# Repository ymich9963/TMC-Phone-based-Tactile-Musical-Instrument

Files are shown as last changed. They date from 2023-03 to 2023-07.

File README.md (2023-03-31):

# TMC: Phone-based Tactile Musical Instrument
A Theremin MIDI Controller made with an HC-SR04 and SingleTact pressure sensors connected to an Arduino Micro. A USB cable is required in order for the hardware and phone to work together.

Created and materialised during the 4th year of my Electronic & Electrical Engineering degree at the University of Strathclyde.

## 3D Prints
Contains the final 3D prints of the project. The bottom part of casing, the top lid as well as the sliding sensor cover.

## Application
Contains the TMC application source files to rebuild and .apk file to directly install on the Android device.

Source code can be edited by donwloading Android Studio and going to File --> Open and selecting the project folder.

APK file can be installed by enabling installation from unknown sources on the device.

## Documentation
Report that details the creation of the project.

## Microcontroller Code
Made in Arduino IDE and can be edited or re-flashed by copying the folders into the default "C:\Users\<USER>\Documents\Arduino\" directory.

Library required is USB-MIDI.

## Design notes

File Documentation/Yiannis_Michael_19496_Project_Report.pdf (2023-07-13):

## Phone Based Tactile Musical Instrument: Theremin MIDI Controller

## Yiannis Michael

### Supervisor: Dr Gordon Dobie Second Assessor: Dr Rory Hampson

### 31st March 2023

“I hereby declare that this work has not been submitted for any other degree/course at this University or any other institution and that, except where reference is made to the work of other authors, the material presented is original and entirely the result of my own work at the University of Strathclyde under the supervision of Dr. Gordon Dobie.”

## Executive Summary

The project encompassed the creation of a phone-based tactile musical instrument.

Following a detailed market analysis and the initial research stage, a proposal was formed

and the project objectives were defined. A Theremin Musical Instrument Digital Interface

(MIDI) Controller was described as the project solution, which would have a theremin

hardware interface and be able to send MIDI commands to ensure cross-compatibility with

other MIDI software. A companion application would also be created to provide interaction

with the hardware as well as using two of a total of three SingleTact sensors for effects on

the sound output. The final product should be able to play a simple melody like “Amazing

Grace”.

The ultrasonic sensor chosen was the HC-SR04 transmitter and receiver, and along with the

three provided SingleTacts, they were the four sensors used in the project. The sensors sent

readings to the microcontroller of choice, which was the Arduino Micro and was coded in the

Arduino IDE. It was chosen due to its capabilities of Universal Serial Bus (USB)

communication, Analogue to Digital Conversion (ADC) and Inter-Integrated Circuit (I2C)

communication. ADC was used for the HC-SR04, and I2C was used for the SingleTact sensors.

All of the components fit inside the custom-designed 3D casing which had four iterations.

The USB protocol was used for the hardware to communicate with the companion phone

application.

The mobile app was made for the Android ecosystem and was therefore designed using

Android Studio and the Java coding language. Examples provided by the Android developers

were modified to fit project needs, and a custom GUI was also designed for user interaction

with the app. MIDI compatibility was accomplished by using and modifying these examples.

In the case of the microcontroller code, the USB-MIDI Arduino library was used to send MIDI

messages to the application. The application gives four effects which can be set to the two

SingleTact sensors, with the third one being mapped for the volume of the note outputs. The

ultrasonic sensor provides note pitch data which is used to send the corresponding MIDI

command for the app to output the specific note. By using the software and hardware

together, as well as all four sensors, it is possible to play music.

The project was a success with all outlined objectives being fulfilled, as well as the completion

of additional objectives which increase the applications of the final product in the real-world

market of phone-based musical instruments.

## Table of Contents

4.3 Results | 62
5.0 Chapter V – Evaluation | 64
5.1 Discussion | 64
5.2 Conclusion | 67
5.3 Further Work | 68
References | 69
Appendix A – Statement Of Intent | 74
Appendix B – Code | 82
B1: Microcontroller Code | 82
B1.1: TMC_2.ino: | 82
B2: Android Application Code | 90
B2.1 SelectionConfig.java | 90
B2.2 MainActivity.java | 92
B2.3 EnevelopeASDR.java | 100
B2.4: SineVoice.java | 103
B2.5: SineOscillator.java | 105
B2.6: SawVoice.java | 107
B2.7: SawOscillator.java | 109
B2.8: SynthEngine.java | 111
B2.9: AndroidManifest.xml | 120
Appendix C – User Guide | 121

## Table of Tables

## Table of Figures

## 1.0 Chapter I – Research

### 1.1 Introduction

In this report it is explained how a phone-based tactile musical instrument was created, with

detailed analysis of each step in its production. In Chapter I, the initial research stage is

expanded upon. This stage gave some ideas as to which paths this project could have taken

and therefore heavily informed the future decisions after this point. Chapter II documents

the hardware chosen and how they are setup for the final product, as well as how they

interact. Chapter III focuses on the project’s software design with both application code and

microcontroller code. The fourth chapter details how testing was made at each stage and

how solutions were created to either completely remove some problems or to minimise their

effect. Final results in this chapter are also described. Chapter V deals with discussion,

conclusion, and further work.

### 1.2 Background

In order to fully understand and appreciate the goals of this product some general

background information about musical instruments, terminology, and history of music must

be explained. A term used in abundance in this report is the Musical Instrument Digital

Interface (MIDI) communications protocol. The creation of MIDI allowed for a standard

instrument language to be used during development. It was developed in the 1980s and

initially proposed by the Roland founder - Ikutaro Kakehashi - to other digital musical

instrument manufacturers who soon got on board and further developed the standard.

Finally, it was released in 1982 and changed the way electronic instruments were developed

for the next decades to come [1].

In modern music a Digital Audio Workstation (DAW), is a must have tool which greatly

enhances the music creation experience. DAWs are music production software that enable

users to record, edit and manipulate audio files in innumerable ways. They also have the

capabilities of manipulating incoming MIDI data, as well as providing some facilities to test

MIDI like virtual musical instruments or custom routing of incoming MIDI commands [2].

However, MIDI and DAWs are only but recent developments in the musical sphere. The main

instrument types that have existed long before them are string, wind, percussion, brass, and

electronic instruments. Examples of these types of musical instruments could be guitar, flute,

piano, trumpet, and synthesisers. In the case of electronic instruments, their manufacturing

process differs from a traditional musical instrument. Instead of considering acoustic

properties, electrical components are used to either program or create a sound output,

either through the instrument itself or through another machine running a software package.

The way the player interacts with electronic musical instruments is usually very similar to

that of a traditional instrument, a good example of this is an electric piano or an electric

guitar [3].

An electronic musical instrument very relevant to this project is the Theremin. This musical

instrument was invented in the Soviet Union by Leon Theremin in 1920. In the analogue

version of the Theremin, the pitch and volume are controlled by the vertical and horizontal

antennae respectfully. The user can move their hands towards or away from these antennae,

each of which have an electromagnetic field surrounding them, and create interference

which in turn affects the outputted sound [4]. Multiple modernised iterations of the analogue

theremin exist today, but other engineers have created much simpler and cheaper versions

using either the same concepts or with other kinds of sensor equipment [5].

Recent developments have allowed the electronic instrument to only use MIDI and MIDI-

compatible software to generate music. This eliminates the use of large and complex

synthesiser circuits and allows for smaller, lighter but still musical instruments called MIDI

Controllers which as the name suggests, are simply pieces of hardware that send or receive

MIDI data to the corresponding MIDI-compatible destination. A MIDI Controller can be a

device of any size and shape and wireless or wired. The only requirement is the ability to

send MIDI data through whatever communications medium it is designed for [6].

Figure 1 Example of MIDI Controller and DAW usage [1]

Some other general musical terminology used throughout this report are “arpeggio” which

is defined as “the notes of the chords are to be played quickly one after another instead of

simultaneously” and “octave” which is used to describe the “interval between one musical

pitch and another with half or double its frequency” [7]. Some other more musical production

terms used are MPC pads which stands for the Music Production Centre pads, used in a

variety of modern electronic musical instruments [8].

### 1.3 Market Analysis

Market analysis was conducted by looking at all major music instrument retailers worldwide,

and seeing what kind of products are being sold that are similar to the project description.

The seven retailers used were Thomann which is based in Germany, Sweetwater and Guitar

Centre which are based in the USA, Swee Lee which have a variety of locations in Asian

countries, Andertons and Guitarguitar which are based in the UK, and finally Ishibashi Music

which is based in Japan. Search terms such as "for iPhone", "for phone", "mobile", "portable"

etc. were used to specifically showcase the products that are phone-based, or can operate

with the phone as well as have other features. The target audience for this market analysis

were musicians of every level whether they would be beginner, intermediate, advanced or

hobbyists, as well as music producers that may not perform with these instruments but use

them in the music making process.

1.3.1 Instruments

There were numerous phone compatible musical instruments that were noteworthy as

shown in Table 1 . The first one was the IK Multimedia iRig Keys 2 (and size variants) [9].

Using a provided software called SampleTank SE 4, the MIDI messages sent from this MIDI

controller can be outputted as sounds depending on the instrument selected, as well as other

functionality customisations. Another MIDI keyboard that was examined, was the IK

Multimedia iRig Keys I/O (and size variants) [10] which also used the "made for iPhone/iPad"

tagline to signify that it was made with those users and that ecosystem in mind . A similar

keyboard found on the market was the CME Xkey Air (and size variants) [11]. One thing that

differentiated this from other keyboards during the market is the “Polyphonic Aftertouch”

capabilities, which means that the note changes timbre while being played.

A more unique take on the MIDI controller is the LinnStrument MIDI Performance Controller

[12] which is an expressive MIDI controller for musical performance. Finally, two very similar

keyboards that were examined were the Akai Professional MPK Mini MK III [13] and the

Novation Launchkey Mini MK3 [14]. These keyboards encompass the idea of a typical

keyboard MIDI controller that is able to be used with a phone, whilst also being portable and

practical. They have the common features all of the previous MIDI controllers had and if

hundreds of generic MIDI controllers were examined, they would be extremely similar to

these two keyboards.

Table 1 Instruments found relating to the market analysis. Features highlight some unique aspects of each instrument.

Product Name | Features | Price | Short Description
IK Multimedia iRig Keys 2 (and size variants) [9] | • Note sustain button • Assignable knobs • Pitch bend wheel • Modulation wheel • Octave up/down buttons • MIDI IN/OUT • SampleTank SE 4 | £113/£130/£149 | Compatible with Android and iOS devices. Used as a MIDI keyboard to control other sounds and plugins.
IK Multimedia iRig Keys I/O (and size variants) [10] | • "Made for iPhone/iPad" • Same features as IK Multimedia iRig Keys 2 • Built in audio interface | £201/£289 | Used as a MIDI keyboard but a built-in audio interface allows another instrument to be connected and used simultaneously.
CME Xkey Air (and size variants) [11] | • "Made for iPhone/iPad", Mac/PC, Android • Octave Up/Down • Sustain Button • Polyphonic aftertouch (only one on the market) • Xkeys Plus (for iOS only) | £159 | Used as a MIDI keyboard to control other sounds and plugins. Xkeys plus used as a companion application for customization.

Table 2 Continuation of previous table.

Product Name | Features | Price | Short Description
LinnStrument MIDI Performance Controller [12] | • Reads and sends MIDI data on pressure, left-right, front-back, release, velocity • Step-sequencer • Customisable Note pads • All previously mentioned features (e.g. sustain and octave buttons) included. | £1399 | A more unique take on the MIDI controller. Used as a MIDI keyboard to control other sounds and plugins; highly customisable.
Akai Professional MPK Mini MK III [13] | • Standard MIDI controller • Arpeggiator • 4-way joystick for dynamic pitch/modulation control • 8 MPC pads • 8 assignable knobs | £77 | Used as a MIDI keyboard to control other sounds and plugins. A generic MIDI controller with most of the common features.
Novation Launchkey Mini MK3 [14] | • Standard MIDI controller • 16 performance tabs • Arpeggiator • Pitch/Modulation strips | £60 | Used as a MIDI keyboard to control other sounds and plugins. A generic MIDI controller with most of the common features.

Figure 2 Image of the Novation Launchkey Mini MK3 [14]

To summarise, on the market there is a limited number of phone-based musical instruments,

and those that are phone=based, are MIDI controllers. There a few that would be suitable to

use with a phone or in generic portable applications. Those discussed above, all share

remarkably similar characteristics with only a few differences that distinguish them. In the

case of the Linnstrument, it is seen that there is demand for other unorthodox MIDI

controllers that can perhaps add unique options to the performance, or the creative process.

1.3.2 Audio Interfaces

One of the most popular peripherals musicians have for the phone is the audio interface [15].

This is not a musical instrument itself, but it is essential for the musical creation process or

the musician’s performance. It sits between the musician’s audio signal and the phone so as

to allow for a data conversion to take place and for recording to happen. The recording can

either be real time to an audience or saved to be processed at a later date.

Two very popular audio interfaces are the IK Multimedia iRig Pro I/O (£149) [16] and the IK

Multimedia iRig Stream (£88) [17]. These devices provide the musician with a minimal audio

recording setup in a variety of scenarios that require portability and short start-up time.

The market research carried out revealed the popularity of these devices, whilst also making

evident that the modern musician is looking to incorporate their phone into their audio

setup. Doing so allows for greater portability and less heavy gear to carry from venue to

venue.

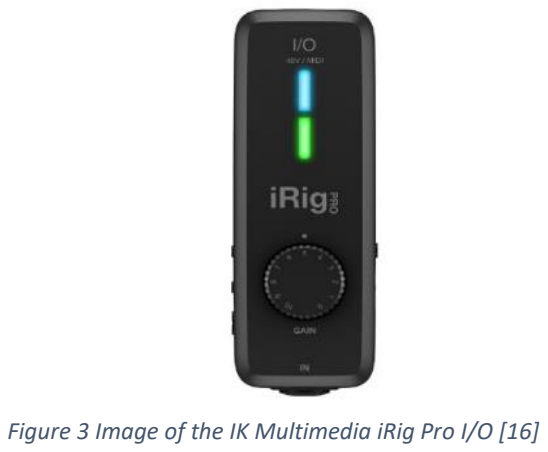
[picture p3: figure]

Figure 3 Image of the IK Multimedia iRig Pro I/O [16]

1.3.3 Apps & Software

There are nearly hundreds of apps available for both Android and iOS ecosystems catered for

musicians, as shown in Table 3. Most of these apps revealed to be MIDI compatible apps

where they either send or receive MIDI messages. This is where a MIDI controller comes into

play, meaning that the apps can process the data sent by the MIDI controller in whichever

way they are set to do so.

Table 3 Applications found during the market analysis.

App Name | Description | Price
Wireless Mixer – MIDI [18] | Can send or receive MIDI messages over WiFi and allow the user to blend their track with other loaded tracks. | Free
TouchDAW [19] | Wireless DAW/MIDI controller that can connect to other MIDI compatible devices wirelessly and either send or receive MIDI data. | Free
MIDI Commander [20] | Extremely customisable MIDI controller in an app format. | Free
MIDI Keyboard [21] | Simple synthesiser/keyboard app that allow the user to play music or to send/receive MIDI data from other sources. | Free
Fluid Synth [22] | Provides the sound libraries required to create music and a MIDI controller is used to play them. | Free
FL Studio Mobile [23] | Advanced DAW experience on mobile. | £14
Cubasis 3 [24] | Advanced DAW experience on mobile. | £27
Sample Tank 4 [25] | a similar concept to Fluid Synth where it acts more as a sound library rather than a DAW. | Free

To conclude, the mobile app market for musicians is dominated by MIDI compatible apps.

This shows how MIDI has been adopted and used in the handheld world, which is far from its

initial beginning in 1982 in wired electronic musical instruments. Apps use MIDI in a variety

of ways, from sending or receiving MIDI commands, to processing these commands and

outputting the sound of a real musical instrument. They complement MIDI controllers and

can be thought of as companion apps that expand the musicians’ possibilities when using

MIDI with a mobile device.

1.3.4 Hardware & Software Packages

Market analysis reveals a variety of devices which are accompanied by an app that allow the

hardware to flourish and show its full potential. Such packages like the LUMI Keys [26] and

the Joué Play [27] have hardware and software that complement each other, but come at a

cost of not working well as general purpose MIDI controllers. LUMI Keys and the

accompanying app are used predominantly as a learning tool while the Joué Play is marketed

more as a music creation tool. Even though the Joué Play is MIDI compatible, packages like it

usually do not have the capabilities to be used in a professional environment and are created

to help hobbyists or beginners understand the music production environment.

1.3.5 Theremin

To provide further background and to further analyse the market, a look at the Theremin

market is necessary. Theremins have existed for a long time with music being written

specifically for them, whether in movie scores [28] or rock songs [29].

The Doepfer A-178 Theremin [30] is a modular synthesiser module that shows how small a

theremin can be with dimensions of 40.3 mm by 40 mm (W x D). A more typical theremin is

the Moog Theremini [31] with its two antennas and extra features, such as variable

quantisation of notes as well as MIDI USB connection. Another product would be the Moog

Clavarox Centennial Theremin [32], which is a premium theremin that also has a MIDI USB

connection.

In general, theremins exist in a variety of sizes with some customisation features and

connections. Using MIDI with a Theremin is an existing concept but it does not exist

exclusively in a MIDI controller format.

1.3.6 Market Analysis Conclusions

To summarise, the market analysis has shown very clear patterns in terms of what type of

musical instruments are used together with a phone. MIDI is a common feature in all musical

instruments examined, and therefore MIDI controllers dominate the market. Most

controllers of this nature are in the piano keyboard format, due to it being one of the most

intuitive and easiest instruments to quickly learn. Other forms of the MIDI controller exist

but they usually do not stray far from what is expected, even though there is a market for

that as well.

The demand for audio interfaces showcases how musicians are very keen in using their

mobile devices for their music setups, whether that would be production or performance.

The largest section of this market is catered towards the iOS ecosystem, due to its

standardisation and quality assurance, with Android still having a share. A variety of apps

exist on both marketplaces that are made for musicians. Apps could encompass playing music

or sending/receiving MIDI messages. Companion apps also allow for custom hardware to

shine and showcase its capabilities; even though they are not used in a professional context,

they still show potential.

### 1.4 Proposal, Aim and Objectives

The conclusions drawn from the background research and market analysis have lead toward

the proposal of a Theremin MIDI Controller (TMC) with a companion Android application.

The connection between the two devices will be using the Universal Serial Bus (USB) standard

as well as the Java language for app development. It will have a minimal 3D design with

simple app customisation. The hardware will be MIDI compatible which will allow for use

with all MIDI compatible software on the market. Discussions of each hardware or software

decision will be made in their corresponding chapters.

As stated in the Statement of Intent and Interim Report, the project objectives are:

- Theremin hardware interface using an ultrasonic transmitter and receiver.
- Make the instrument able to send MIDI commands in order for it to be used in other

applications.

- Application created to provide phone interaction with instrument.
- Ability to play a simple song like “Amazing Grace”.
- Implement three SingleTact sensors, with two designated for effects.

Figure 4 High level diagram of the Theremin MIDI Controller

The theremin functionality will be accomplished with a distance sensor and the SingleTact

sensors which will employ the user’s hand for input. This input will be processed through a

microcontroller and sent to the phone through a wired connection. The app will then process

this transmitted data and give the corresponding output.

### 1.5 Planning

1.5.1 Initial Gannt Chart

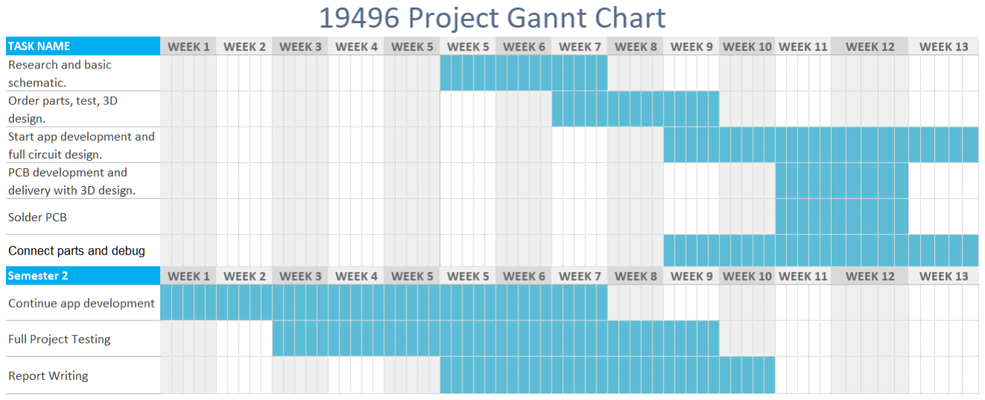
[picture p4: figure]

Figure 5 Initial Gannt Chart. Each box reflects a day in a week. Error in semester two week five label, but cannot

be changed since it is an old image.

An initial Gannt chart was created (Figure 5) and time was allocated based on it. Three weeks

were allocated for research and to create a basic schematic. Three weeks were also allocated

to order parts and to start designing the casing for the product. Based on this initial chart, at

Week 9 the app and full circuit design should have started and initially take around four to

five weeks or until the first semester ends. The same amount of time would be allocated for

connecting the parts and debugging the project as it progresses. While both previous tasks

are happening, PCB development, soldering and 3D design of the casing will also be

occurring. In semester two, the app development would continue until Week 7 with full

project testing starting in Week 3. Both will finish in Weeks 7 and 9 respectively. Report

writing should start in Week 6 (mistake in figure) and continue until the end of the project.

This chart was updated roughly around Week 9 of semester one so this structure was roughly

followed until then.

1.5.2 Final Gannt Chart

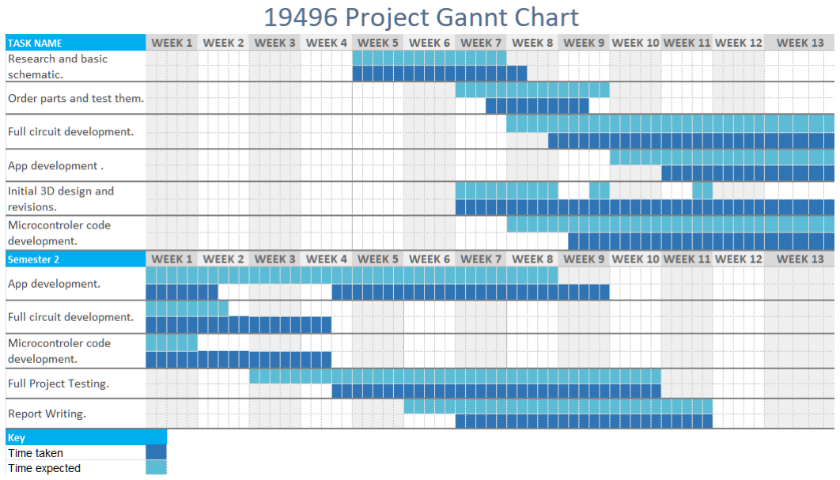
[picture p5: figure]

Figure 6 Final Gannt Chart. Dark blue is time taken and light blue is time expected. Each box represents a day

The Gannt chart was then revised before the end of the first semester (Figure 6), and due to

having a better understanding of how the project will progress, more tasks were created and

time was allocated more effectively. After the initial research stage, it was concluded that no

PCB would be required, and that the project would take a more software-centric approach

to make it easier to manage in the later stages were time is critical. Ordering of components

or finding problems with compatibility near the end of the project with a hardware-centric

approach could prove extremely difficult to resolve.

Same time was allocated for initial research and ordering parts. Then, full circuit

development would start in Week 8 and continue until around Week 2 of semester two. One

section each was allocated for the mobile application development and the microcontroller

code development, with the microcontroller section taking around the same time as the full

circuit development. App development should start a week after full circuit development and

continue until Week 8 of semester two. The 3D design should start early on in semester one

Week 7 and finish by the end of the semester. Full project testing should start near the

beginning of semester two and around one week before the report writing in Week 10.

Report writing should also be done at the same time as full project testing and app

development but should start in Week 6 of the second semester.

Overall, the planning of the project allowed for extra time when setbacks occurred. Major

obstacles were in Weeks 2 to 4 of semester two where there was an issue with MIDI detection

on the Android phone, so microcontroller code development and full project testing was

extended by two weeks. The app development was experiencing little progress during the

same timespan due to issues with the Java code. Another setback was the learning curve of

using 3D Computer Aided Design (CAD) software, since no previous experience was had with

such design applications. These issues are expanded upon in their respective sections, but in

the end they did not severely affect the completion of the project objectives. Everything was

completed on time and as planned

### 1.6 Budget

Figure 7 showcases where the budget was allocated, as well as the prices for the components

(HC-SR04 [33], USB Type-C Adapter [34], USB Type-C cable[35] and Arduino Micro [36]) and

how much they took from the budget. With this chart it is safe to conclude that this project

was well within budget.

### 1.7 Project Motivation

This project aligns with my career aspirations which are to work in musical instrument

production as well as embedded system design. It also will enhance my skills in product

design and general programming. There is nothing like it on the market and therefore it is

also an area worth exploring and expanding upon.

Figure 7 Chart showing budget allocation

## 2.0 Chapter II – Hardware

### 2.1 Component Selection

Choosing which components to order and use, was reliant on the direction the project would

take. If more advanced hardware was used then more unusual hardware would be chosen

for the project. For example, a microcontroller programmed with In-Circuit Serial

Programming (e.g. MSP430F5500 [37]) could have been used, along with a USB Host

integrated circuit (e.g. FT312D [38]), and custom PCBs and soldered USB connectors. This

route was decided on being too time consuming due to completely new approaches to

programming hardware and data communication. Also, it would have been harder to debug

in late stages of development where a wrong or faulty component could jeopardise the entire

project.

Thus, the route taken and detailed in this report is the advanced software route, where

simpler hardware was chosen and advanced or new programming techniques to complete

the project objectives were adopted instead. This would make the product easier to debug

and test in the late stages since the hardware could be completed early on; it would also be

cheaper due to simpler hardware being less expensive and less likely to have

incompatibilities. Libraries and examples of difficult programming challenges are also

available online and could therefore be used to further decrease the difficulty of objective

completion.

Figure 8 Diagram of TMC components and their interaction

2.1.1 Distance Sensor

The distance sensor selected was the HC-SR04 Ultrasonic Distance Sensor. It was chosen due

to being a receiver/transmitter combination in a single PCB. The working current and voltages

(30 mA and 5 V respectively) are sufficient to be powered by a small microcontroller. The

range of 2 cm to 4 m is also more than enough for simple hand detection. The Vcc , Trigger,

Echo and Ground pins have headers which can be connected to a microcontroller, with male

pin headers using female to female header cables. An Analogue to Digital Converter (ADC)

was used to convert the readings to a useable format in the microcontroller code [33].

2.1.2 SingleTact Sensors

These pressure sensors were a must for the project due to one of the objectives stating to

use at least two SingleTact pressure sensors. A third sensor was added bringing the total up

to three to make the hardware a more complex. A choice between 4.5 N, 45 N and 450 N

force ratings had to be made. Using a food scale to find the strength required for the specific

ratings, the 4.5 N model was chosen as the most suitable. One SingleTact sensor has a supply

voltage and current of 3.7 V to 5.5 V and 2.7 mA respectively. Furthermore, the

communication method used to receive data from the SingleTacts was Inter-Integrated

Circuit (I2C). [39]

2.1.3 Microcontroller

The microcontroller chosen was an Arduino Micro. This decision was influenced by the need

to have USB data transmission, an ADC for the Ultrasonic Sensor data and to use I2C for the

SingleTact sensors. As well as being one of the smallest units in the Arduino range, it checks

all the boxes. It has seven pins for ADC conversion which one will be used to read data from

the HC-SR04.

Table 4 Different requirements for the components used.

Component | Amount | Current Required (mA) | Voltage Required (V)
HC-SR04 | 1 | 30 | 5
SingleTact Pressure Sensor | 3 | 2.7 | 3.7 – 5.5

Based on Table 4, a voltage of 5 V and a total current of 38.1 mA are required to power all

components. The Arduino Micro can provide 5 V and 50 mA max from its 5 V pin, making it

ideal for supplying power to the components. [40]

2.1.4 Mobile Phone System

Due to having a personal device using the Android operating system, it was preferred to use

an Android phone as the type of mobile phone the final product would connect to. Therefore

the Android phone used was a OnePlus 9 with Android 13.

### 2.2 Wiring

Using female to female, and female to male header cables were the main ways this project

was wired. All cables were soldered to accommodate the project’s needs for a compact

system. A wired USB Type-C cable [35] and a USB Type-C Female to Micro USB Male Adapter

[34] was used in order for the specific cable to connect to the Arduino Micro’s USB port. A

USB Type-C connection between the microcontroller and the phone was chosen due to the

growing market of USB Type-C devices. Using an adapter only provided the reversible

benefits of this type of USB and not the data transmission or power benefits, this is due to

the Arduino Micro only being USB 2.0 capable [40].

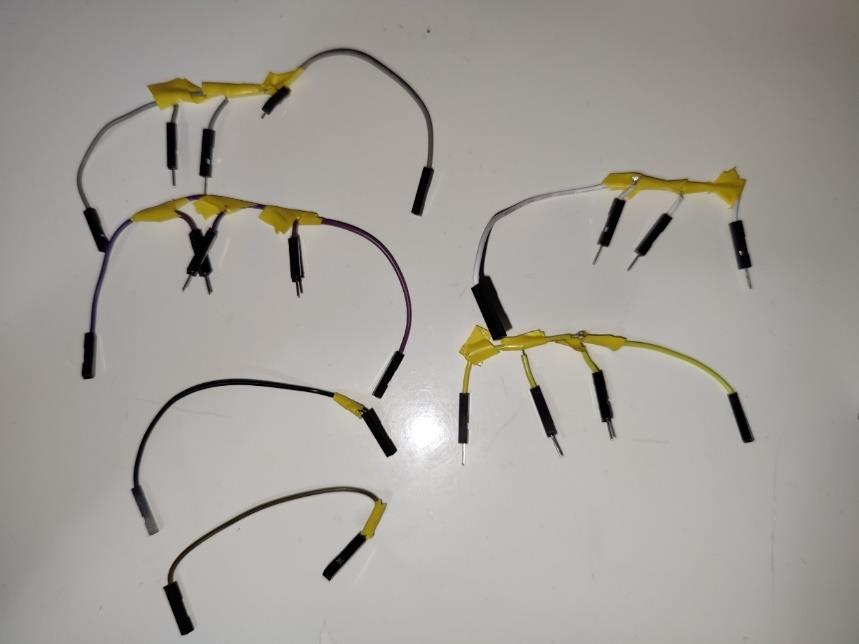
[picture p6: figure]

Figure 9 Custom wiring. From left to right are the following wires: Voltage, Ground, SDA, Trigger ,SCL, and Echo.

2.2.1 Voltage and Ground

Wires for providing a voltage source and grounding were custom wired using six male header

cables and four female header cables. Insulation tape was added to all solder joints prevent

shorting. In the voltage wire, the three male header cables are for the three SingleTact

sensors, and one of the female headers is for the HC-SR04 voltage pin. The remaining female

header is for the Arduino Micro 5 V pin which provides the required voltage supply for all the

components to function. Similarly, the ground wire has the same connections, but it connects

to the Ground pin of the Micro [40].

In the case of the SingleTact sensors a male header is inserted into pin 1 for the voltage and

into pin 8 for the ground [39]. Whereas, for the HC-SR04, the female header is used and is

inserted into the Vcc and Ground pins, to provide a voltage and ground respectively [35].

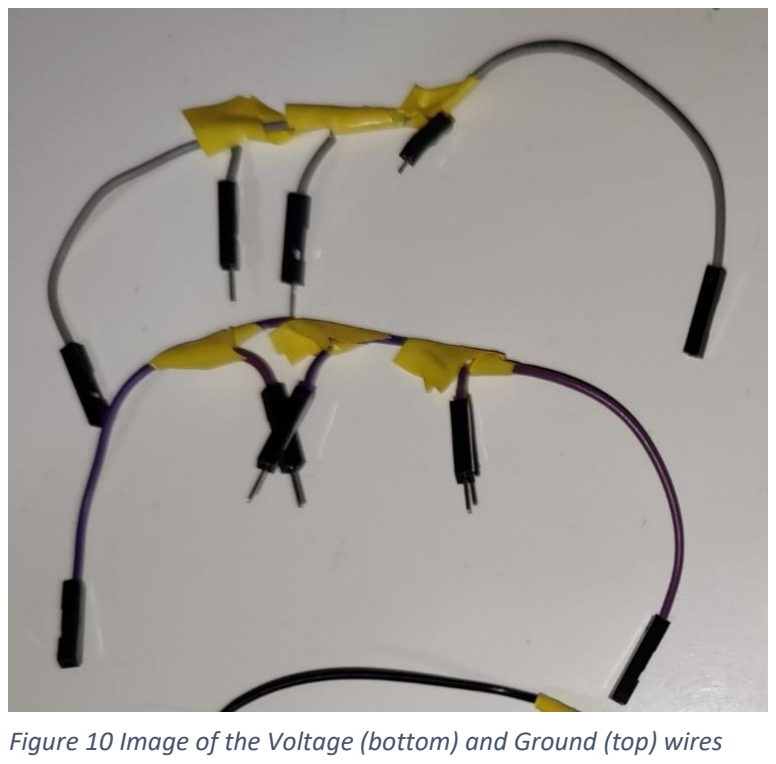
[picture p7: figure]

2.2.2 Data transfer

Communication between the sensors and the microcontroller occurs with four wires. Custom

wires were made for the Serial Clock (SCL) and Serial Data (SDA) connections required for I2C

to happen. The three male headers go into the SCL and SDA pins of the SingleTacts. Another

pair of wires is used to connect the HC-SR04 Trigger and Echo pins to the corresponding pins

on the Arduino Micro.

Figure 10 Image of the Voltage (bottom) and Ground (top) wires

The male header of the SDA and SCL wires are inserted into pins 6 and 3 of the SingleTacts

respectively [39]. These two wires allow for I2C communication between the microcontroller

and the sensors. Pin D2 is the SDA pin for the Arduino Micro and D3 is the SCL pin. The

corresponding female pin header is inserted into these two pins to allow for the connection

to be complete. For the HC-SR04, the wire connected to the Trig pin gets connected to pin

A1 of the Micro and the Echo pin is connected to the A0 pin. The output of the pins mentioned

was configured in the Microcontroller code. The final wiring is shown in Figure 13.

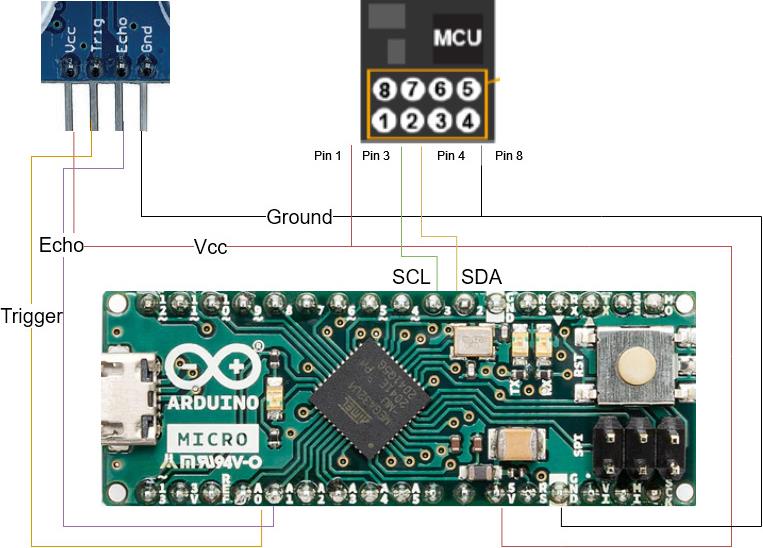
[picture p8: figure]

Figure 13 Full circuit diagram of inner wirings of the TMC. Connections to the Arduino Micro and HC-SR04 are visualised, while on SingleTacts the pin numbers are displayed.

Figure 11 Image of SDA and SCL wires for the SingleTact sensors

Figure 12 Image of Trig and Echo wires for

### 2.3 3D Design

The casing was designed using Autodesk Fusion 360, which is 3D Computer Aided Design

(CAD) software. Four main prints were made with a final print (Print 5) being planned if the

project finished early. Pre-existing 3D designs for the Arduino Micro [41], HC-SR04 [42] and

the HC-SR04 holder [43] were downloaded from the appropriate sources. Custom designs

were created for the SingleTact sensors and the USB Type-C adapter by measuring them and

creating diagrams (see Figure 19 and Figure 18). These components were needed in order to

understand the space they would occupy, and how they would all fit together. The design

focused on portability and ergonomics, though it was inevitably constrained by the Arduino

Micro headers, space taken by the wires, and the flat surface required by the HC-SR04 and

SingleTacts.

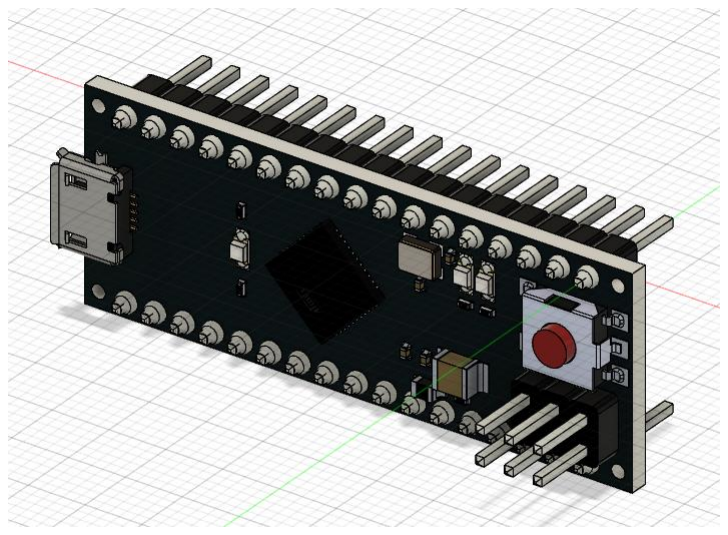
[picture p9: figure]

Figure 15 3D CAD model of the Arduino Micro [40] | Figure 14 3D CAD model of the HC-SR04

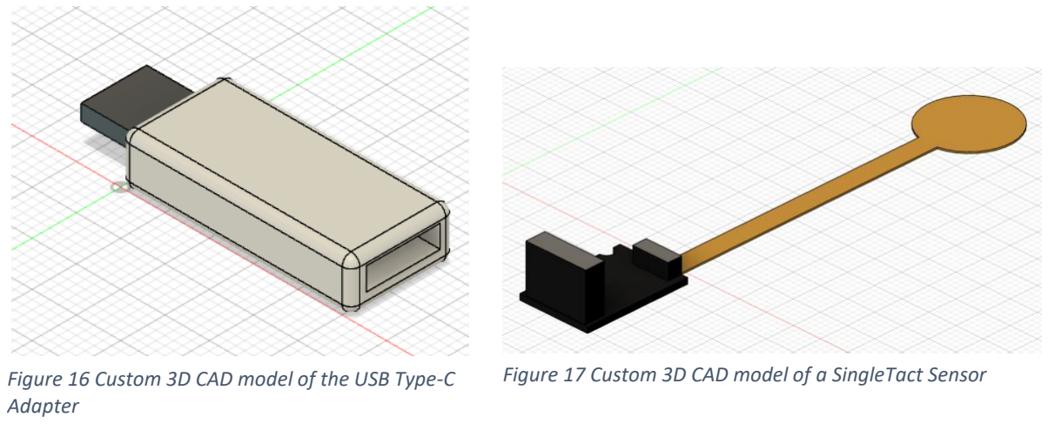
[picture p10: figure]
Adapter

Figure 16 Custom 3D CAD model of the USB Type-C

Figure 17 Custom 3D CAD model of a SingleTact Sensor

2.3.1 Initial Concepts

Shown below are some initial concepts that were first drawn, considered, and then designed

in Autodesk Fusion 360 for a better understanding of the dimensions, and ergonomics of the

product.

Figure 19 Initial measurements and sketches of USB Type-C Adapter

Figure 18 Initial measurements and sketches of a SingleTact

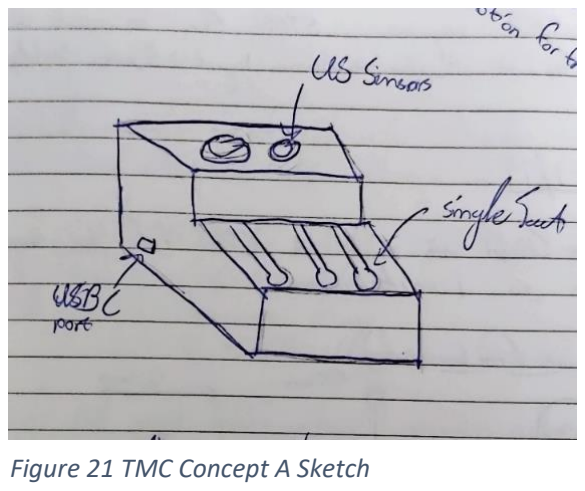
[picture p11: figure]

Figure 21 TMC Concept A | Figure 21 TMC Concept A Sketch

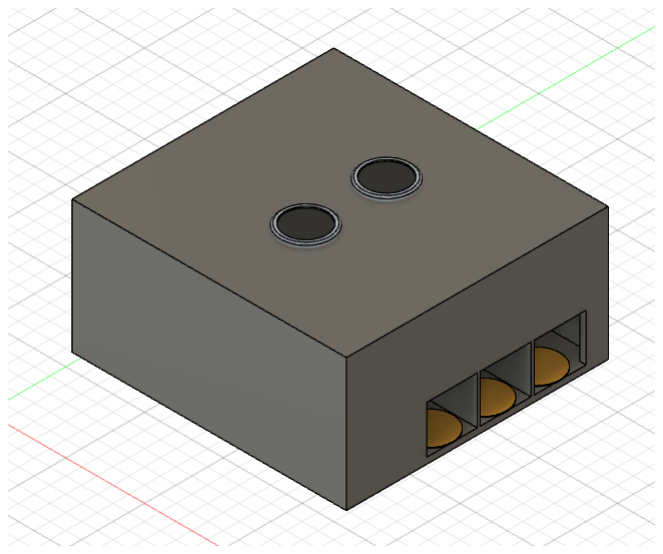
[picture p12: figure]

After careful consideration, TMC Concept C (Figure 24) was the one declared most suitable

for printing. The SingleTact sensors would be on the bottom as shown, and the HC-SR04

would protrude from the top to allow to distance detection. The Arduino microcontroller

would be to the left of the pressure sensors, with a USB port hole designed at the back of the

casing. Some modifications had to be made in order for the components to be fitted inside

and allow for further inspection. Therefore, this design was adapted with a sliding-up sensor

front cover and a top lid which resulted in Print 1.

Figure 22 TMC Concept B | Figure 23 TMC Concept B Sketch
Figure 25 TMC Concept C | Figure 25 TMC Concept C Sketch

2.3.1 Print 1

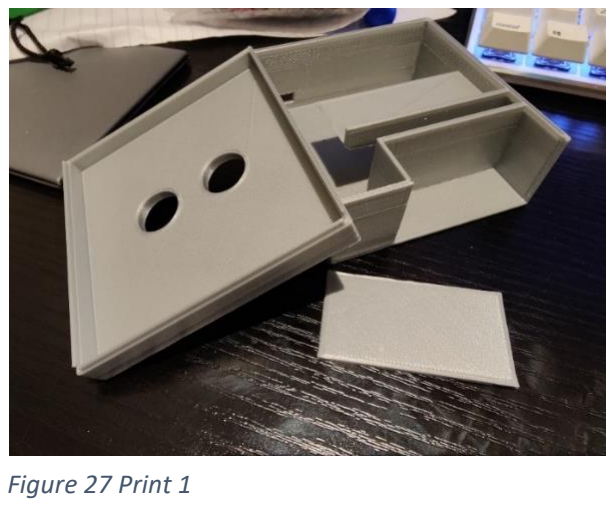
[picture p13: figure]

Print 1 (Figure 27) was the first printed concept which gave a lot of insight into how the

product should be improved in future prints. It had a lot of issues which meant improvements

and a second print was to be scheduled. The issues include insufficient space for the Arduino

Micro, hole for USB port was too small, HC-SR04 sensor hole was too small, no way to have

SingleTact sensors stay in place and no holes at the front for them to stick out and be useable.

The dimensions for Print 1 were 87 x 83 x 42 mm (W x L x H). These dimensions remained the

same for Prints 2 and 3.

Figure 26 3D CAD Design of Print 1 | Figure 27 Print 1

2.3.2 Print 2

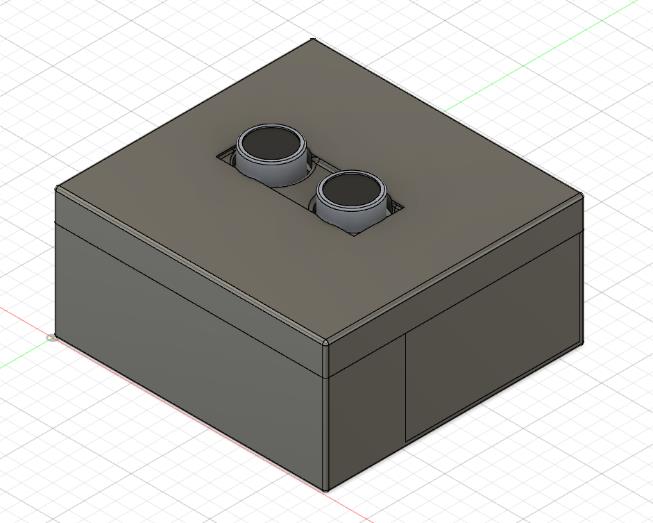
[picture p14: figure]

For Print 2 (Figure 28), the issues of Print 1 were resolved, but other issues also arose which

prompted Print 3. The HC-SR04 shelf was rotated by 90◦ to make more space for the

microcontroller headers, and a stop bar was added to hold the SingleTact sensors in place.

Larger holes for the USB port, the HC-SR04 and SingleTact sensors were also designed.

The issues were that the Arduino Micro and the HC-SR04 were not able to remain horizontal.

This was especially important for the HC-SR04, since it should be completely horizontal in

order to accurately measure distances. The shape of the product was also not aesthetically

pleasing and therefore some aesthetic changes would have to be done in the next print.

Figure 29 3D CAD Design of Print 2 | Figure 28 Print 2

2.3.3 Print 3

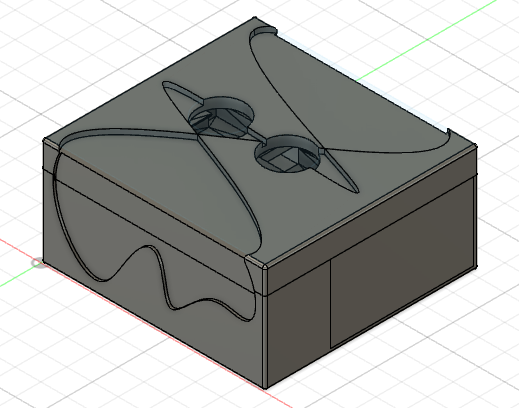
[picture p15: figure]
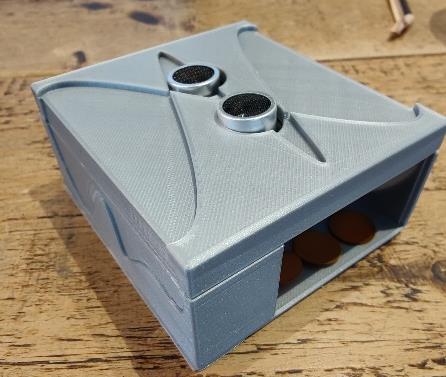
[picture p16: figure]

Print 3 (Figure 30) improved on the issues mentioned in Print 2, however more issues needed

to be addressed. The HC-SR04 holding bracket (Figure 33) downloaded from Thingiverse [43],

allowed for the ultrasonic sensor to be stable and horizontal at all times. A small block was

also added for the Arduino to sit on and be able to stand horizontally. Some aesthetic changes

were also made to the outside of the casing to make it more aesthetically pleasing.

Figure 31 3D CAD Design of Print 3 | Figure 30 Print 3

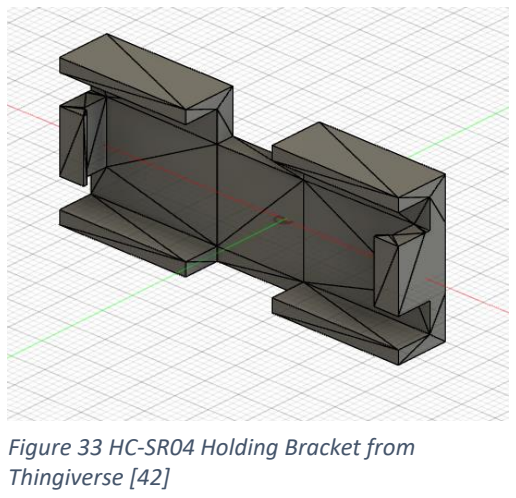
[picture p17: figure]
Figure 33 HC-SR04 Holding Bracket from Thingiverse [42]

Figure 32 Top View of Print 3. The new holding bracket can be seen in the middle and the block for the Arduino

The issues with this print were that the walls were now too thin due to the new exterior

design. This made the lights of the Arduino be able to shine through, and the casing now felt

fragile. This print revealed that more space for the wiring was required, meaning it had to be

made bigger and with thicker walls. The sliding sensor cover at this point could only be

removed upwardly, but that meant the user always had to remove the cover and reveal the

wiring in order to play with the TMC. As this is both a musical instrument and a product, this

had to be remedied by creating a sliding cover that goes to the right which would allow the

opening and closure of the sensors without exposing the wires.

2.2.4 Print 4

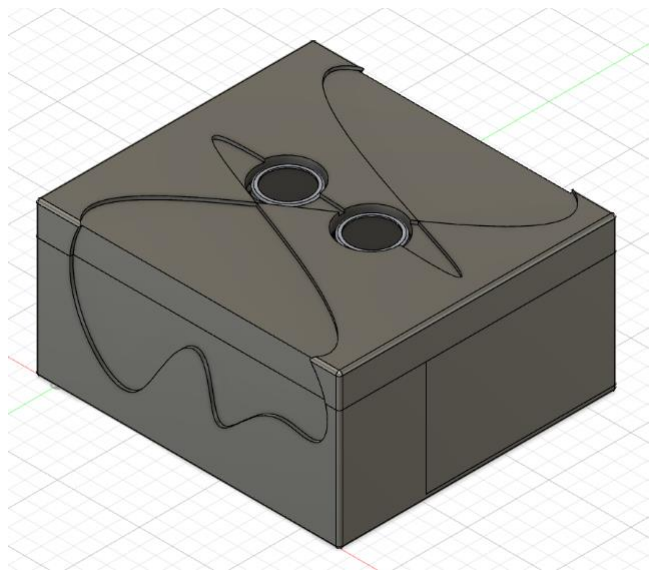
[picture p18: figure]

Print 4 proved to be the best and final print. It was a bigger version of Print 3 with a sliding

sensor cover, an obstacle to keep the microcontroller in place and thicker walls. These new

features are visible in the top view when comparing Print 3 (Figure 32) with Print 4 (Figure

36). The finalisations made to this print after it was printed were, double-sided tape added

to keep the SingleTacts from moving, and hot gluing the Arduino in place so it stays still. There

are no major issues to this print but improvements could be made and some are noted in

Print 5. The dimensions of Print 4 are 92 x 85 x 47 mm (W x L x H) with height being 57 mm

with the HC-SR04.

Figure 34 3D CAD Design of Print 4

Figure 35 Print 4

2.2.5 Print 5

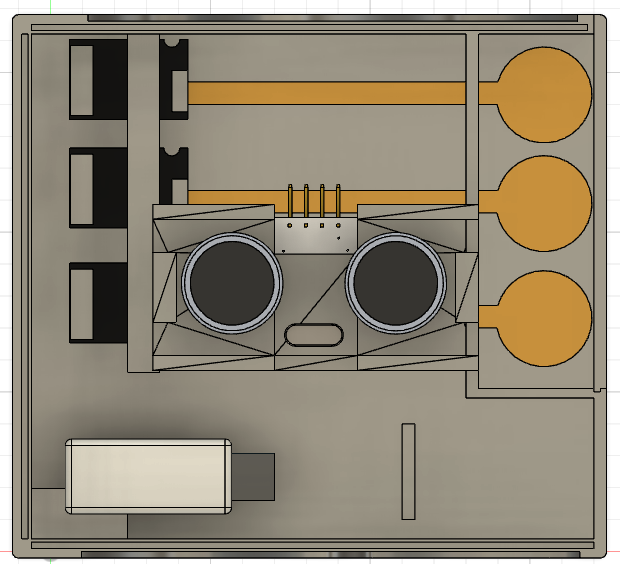
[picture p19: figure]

Print 5 was not completed due to other project objectives taking priority. Print 5 would have

incorporated an indicator LED to show to the user if data is being read or sent. A screw would

also be situated at the top lid to further prevent the user from opening the TMC and exposing

the wires. Print 4 is acceptable and fully incorporates all the needs of the final product so a

fifth print was not needed.

### 2.4 Hardware Issues

Even though the hardware helped fully accomplish all project objectives, some issues did

occur and had to be dealt with accordingly. The issues with the casing of the TMC were noted

in section 2.3 for each print specifically.

One critical issue was also one SingleTact sensor not outputting the expected readings. This

was discovered when it was being tested during code development, and more detail as to

how it was discovered will be in Chapter IV. To resolve the issue, a new sensor was given by

the manufacturer. Moreover, the SingleTact sensors were not calibrated and also moved

during use. Double sided tape was used to keep them in place, and the built-in Arduino

“map()” function was used to calibrate their values as best as possible. This will be detailed

in the Software Development section.

Figure 36 Top view of Print 4. Obstacle for the microcontroller can be seen at the bottom as well as the thicker walls and the new sliding sensor cover

Another issue of note is the accuracy of the HC-SR04 when using a surface such as a hand

that is irregular and soft. This specific sensor is also very sensitive to noise from ultrasonic

wave reflections, that are not from the object being measured. There was an attempt to

combat this by using a rolling average when gathering measurements. This will be examined

further in Chapter IV.

The Arduino Micro also was prone to moving around in the casing. It was temporarily

remedied with a small sponge, before it was hot glued in place. On the wires, glue on the

insulating tape wore out over time and this can be helped by using a better insulation tape.

The wires for the Trigger and Echo pins also had a weak point at the solder joint which

prompted a re-soldering of the wires. Both were soldered in a similar manner as before but

more in the middle of the wire, and for one of them a heat shrink was used (Figure 37).

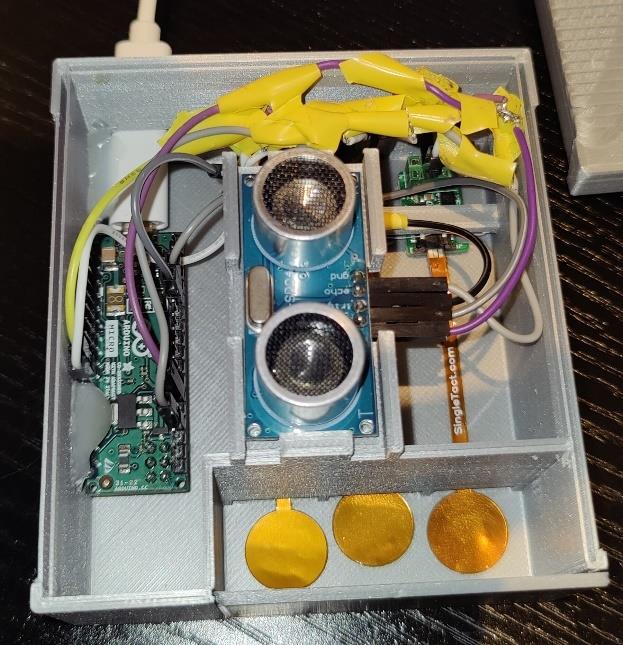
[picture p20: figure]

### 2.5 Component Alternatives

One other possible solution for the distance sensor, was the Devantech SRF08 Ultrasonic

Range Finder [44]. This sensor can provide I2C communications with the microcontroller unit,

but due to the massive price difference, and to help keep the I2C bus as free as possible from

unnecessary transmissions, the HC-SR04 was chosen instead.

Multiple Arduinos were taken into consideration when deciding which microcontroller to

use. Other suitable models were the Arduino Uno rev3 [45] and the Arduino Due [46] with

its extra programmable USB port, but to make the final product more portable, and to not

waste extra features, the Micro was chosen instead.

Figure 37 Re-soldered wire. Moved the solder joint and a heat shrink was used.

Figure 38 Picture showing glue and double-sided tape. Glue can be seen on the top left which holds the Arduino in place. SingleTacts could only lie flat as shown with the double-sided tape added.

## 3.0 Chapter III – Software

### 3.1 Communication Methods

Multiple communication methods were used in this project. In particular, there were two

ways in which the sensors communicated with the microcontroller, and another two ways in

which the phone and the microcontroller communicated.

3.1.1 USB and MIDI

These two methods were used together simultaneously for communication between the

mobile phone and the Arduino Micro. To accomplish such a task, the Arduino MIDI-USB

Transport Library [47] was used. This library incorporates and handles the bulk of the work

for both the MIDI and USB functionality required in order for the phone and Arduino to

communicate with a wired USB connection for MIDI data.

MIDI data is usually referred to as MIDI messages or MIDI events when talking about a

message at a particular point in time. They carry information about which MIDI command is

being sent, as well as one or two values related to that command. For example, when sending

a Note On MIDI Message, the first parameter is the value “0x9” and the next two parameters

are the note number (or note value), and the intensity of the note which is called velocity

[48]. There are hundreds of MIDI commands, and some are even custom made for a specific

MIDI instrument. MIDI even supports up to 16 channels for multiple MIDI event handling at

the same time, but this project only used channel 1 (or 0) for simplicity [1]. The event types

used in this project and their parameters are shown in Table 5.

Table 5 MIDI event types used in the project

Event Type | Event Value (hexadecimal) | Parameter 1 | Parameter 2 | Description
Note On | 0x9 | Note Value | Velocity | Used to turn notes on/off based on their note value. Velocity determines the intensity of the note. Parameters 1 and 2 range is from 0 to 127 [49].
Note Off | 0x8
Pitch Bend | 0xE | Value LSB | Value MSB | Used to change the pitch of the note in the current channel. Each parameter value is 7 bits long which makes up a 14-bit number. Range is from 0 to 8192 in each value. A total value of 8192 means no pitch bend [48].
| | Number | | Controller numbers used are only the ones listed. Sent when it is needed to change the MIDI channel state [50].
| | 0x07 | | Volume – By default changes the volume in an application. In the TMC app it is mapped to the velocity.
| | 0x0C | | Effect Control 1 – Is usually mapped to an effect by default in many applications. It had a similar application in the project.
| | 0x0D | | Effect Control 2 – Same as Effect Control 1.

Control

Change

0xB | Controller

Controller

Value

3.1.2 I2C and ADC

Inter-Integrated Circuit and Analogue to Digital Conversion are the other two communication

methods used in this project. I2C is used for reading data from the SingleTact sensors and

ADC is used when receiving readings from the HC-SR04.

The I2C serial communications protocol is used for short distances with a single (or multiple)

device(s). Two wires are required to exchange information between two devices, with

multiple wires used when multiple “peripherals” or “controllers” exist on the same bus. A

peripheral can communicate with a controller where the controller reads or writes to, or

from, the peripheral. One wire required is called the Serial Data and the other is called Serial

Clock. The clock signal is sent by the controller to synchronise all of the peripherals on the

bus together. Addresses are assigned to the devices connected to the bus so that data

reaches the correct destination. Pull-up resistors are required to keep the bus signal to high,

so that no unnecessary power dissipation occurs and no damage is caused to the connected

devices [51].

This I2C functionality within the Arduino Micro is handled by the Wire [52] library. Peripheral

addresses are assigned to the SingleTact sensors using the address change Arduino project

provided [53]. It is also responsible for enabling the pull-up resistors.

ADC conversion happens by detecting the voltage at the designated pin and converting it to

a digital binary value [54]. In the case of the Arduino Micro, a 10-bit resolution is provided

[40] and can be used by assigning input and output pins with the “pinMode()” function [55].

For the HC-SR04, using the “pulseIn()” function [56] will also assist when detecting pulses

between 10 microseconds and 3 minutes in length. More detail with regards as to how these

functions are used and their role in the microcontroller code is described in the

microcontroller code section.

### 3.2 Microcontroller Code Development

The code for the functionalities of the Arduino Micro can be found in Appendix B1. The main

sections will first be explained and then each individual function will be expanded upon.

3.2.1 Definitions and Variable initialisations

Lines 1 to 52 are the main definitions and global variable initialisations that are used

throughout the project. Lines 1 and 2 include the main libraries used by the Micro which are

“Wire.h” and “USB-MIDI.h”. Line 4 creates a default MIDI USB instance for the Arduino Micro

which allows for it to be used and viewed as a MIDI peripheral device. Lines 6 to 24 define

certain values that are used as constants and the definitions provide for easier readability

and debugging.

From Lines 27 to 52 the global variables are declared and initialised to zero. In Lines 51 and

52, function prototypes were listed due to errors given by the Arduino compiler regarding

these functions.

3.2.2 Setup Section

The “setup()” section of the Arduino code is for initial setups, and is only ran once in the

entire program. At Line 55 the Arduino pins are setup so that they can communicate with the

HC-SR04. The next 4 lines are to initialise the MIDI connection on channel 1, begin the I2C

connection, and start a serial connection of a 31250 samples/s baud rate [57].

3.2.2 Main Loop Section

In the “loop()” section is where the main program is run and is continuously looped. The first

code that is executed is the “measuredAndCCsend()” function. This function reads all

measurements from the connected sensors and sends the Control Change (CC) MIDI

Messages using the SingleTact sensor data. This being outside of the main if-statement allows

the TMC to also be used as a MIDI Effects controller.

If the measured distance is less than the defined maximum distance, then the MIDI

functionality is executed. Firstly, the idle state of the TMC is reset and the measured distance

is entered to the “buffer[]” array. The array becomes populated at each iteration of the loop

and the average is calculated each time. A weighted average was attempted but proved to

be of no benefit, so the raw data is not added to the final result and is instead multiplied by

zero. The current note is then the current weighted average distance based on the output of

the “noteOut_Cmaj()” function.

Lines 75 to 94 are where the MIDI messages regarding the notes are calculated and sent. If

the current note is not the same as the previous note, then the previous one is turned off,

and the next one is sent. Lines 80 to 93 are not used in the final version of the project and

are there to facilitate future work. At the end of the iteration, the previous note becomes the

current note. This is in order to compare the different notes being played and to decide when

to send a different note.

If the measured distance is more than the maximum distance, the idle counter is iterated to

signify that the TMC is inactive. Once it has reached the value of 100, the TMC is reset. The

pitch bend mode value is reset as well but this is not used in the final version of the product.

3.2.3 Functions: setupUSR()

In this function, the pinouts of the Arduino Micro for the HC-SR04 are specified. Using the

definitions and the “pinMode()” function, pins number 18 and 19 are set to be INPUT and

OUTPUT respectively.

3.2.4 Functions: getDistance()

At each iteration of the function, the variable to store the distance is set to 0. Using the HC-

SR04 specification [33], the “digitalWrite()” function and a delay, the correct wave signal is

sent in order for a received signal to occur. A short LOW pulse of 2 μs is given to the trigger

pin and it is followed by a HIGH pulse lasting 10 μs, which is then set to low once that amount

of time has passed. Using the provided equation in the specification and the “pulseIn()” [56]

function, the distance of the object reflecting the ultrasonic wave is measured. It was found

experimentally that the HC-SR04 rarely reached zero, so a distance offset is subtracted from

the measured distance to remedy that. The measured distance value is then returned.

3.2.5 Functions: readDataFromSensor()

This function was referenced from a provided example Arduino file [58] and is used to read

data from a SingleTact sensor using the I2C communications protocol. The addresses used

are “0x06”, “0x08” and “0x0A”. More info as to how the SingleTact sensors handle I2C

packets can be find in sections 2.3 and 2.4 of the SingleTact user manual [59].

3.2.6 Functions: testSensorOutputs()

It is used when testing sensor data. Outputs are printed in the Arduino IDE serial monitor and

it will be showcased in the testing section of this report.

3.2.7 Functions: noteOut()

Using this function allows for the MIDI note values to be calculated, and used in MIDI Note

On or Note Off messages. The upper and lower bound of the range of detection for each note

is calculated by equations (1) and (2),

LB = Range × (Note Number − 1) | (1)
UB = Range × Note Number − 1 | (2)

Where Note Number is the values 1 through 13 to signify a full octave of notes to be played,

and Range is the number defined as “range_cm” in the definitions. It was found

experimentally that the optimal number for this is 4.

The notes outputted by this function are shown below in Table 6,

Table 6 MIDI Note Numbers and Notes outputted by the noteOut() function [49].

MIDI Note Number | Note | MIDI Note Number | Note
48 | C4 | 56 | G#4
49 | C#4 | 57 | A4
50 | D4 | 58 | A#4
51 | D#4 | 59 | B4
52 | E4 | 60 | C5

53 F4

54 F#4

55 G4

3.2.8 Functions: noteOut_Cmaj()

Similarly to the “noteOut()” function, this has the exact same functionality but it is tuned to

play the C major scale instead of outputting all of the notes in an octave. This allows for a

more Western and “in-tune” note selection. The MIDI note numbers outputted are therefore

48, 50, 52, 53, 55, 57, 59 and 60.

3.2.9 Functions: popBuffer()

When a distance value is measured, it is inputted in this function and gets added to the

distance buffer array. The function works by duplicating the value in the current index

starting from the last index, and moving it to the right by one. This allows for the first index

of the array to be a duplicate of the second, and could therefore be replaced by the inputted

distance value. An example of how this function works can be found in Figure 39.

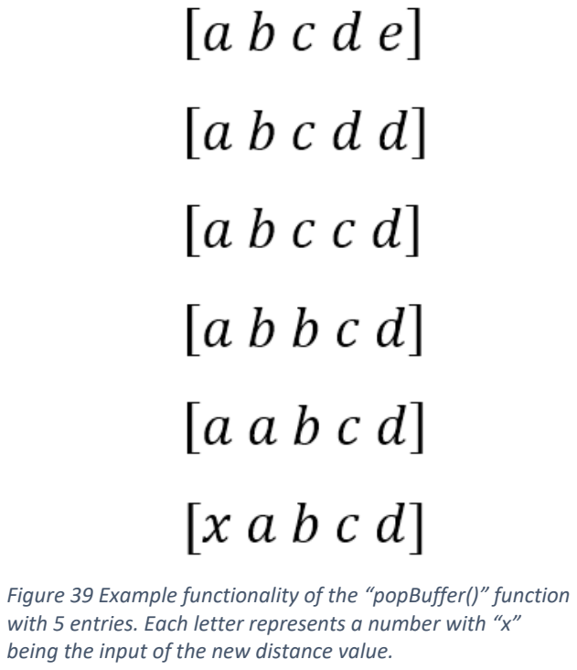
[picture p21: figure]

3.2.10 Functions: calcAvg()

The average is calculated using this function. It is done by iterating the buffer array based on

the desired buffer size and adding all of the values to a single variable. This variable is then

divided by the buffer size to get the average.

Figure 39 Example functionality of the “popBuffer()” function with 5 entries. Each letter represents a number with “x” being the input of the new distance value.

3.2.11 Functions: reset()

Resetting most of the required variables is done by this function. Firstly, it turns the TMC off,

and then iterates each MIDI note number to turn the notes off using the “sendNoteOff()”

function.

3.2.12 Functions: measureAndCCsend()

This function is the first one executed in the main loop. It firstly calls the “getDistance()”

function and assigns its value to a variable. Then the value of each SingleTact sensor is read

using the “readDataFromSensor()” function. Due to MIDI requiring event data to be between

0 and 127, the “map()” function is used [60] to map the received SingleTact values. These

values are between 256 or 260 and 1022, due to the sensors being uncalibrated. The

minimum outputted value of the SingleTact sensors was observed experimentally per sensor,

and the minimum value of the function was set on based on that.

To minimise noise, the values above 4 are used to send MIDI Control Change (CC) data. CC

data is sent using the “MIDI.setControlChange()” function at MIDI Channel 1. The CC values

sent are 7, 12 and 13 as seen on Table 5. If the values are not more than 4, then the received

data is set to be 0 in order to reset its value.

3.2.13 Flowchart

Figure 40 High level flowchart of microcontroller code. Rectangular boxes are actions and rhombus shapes are checks.

### 3.3 Application Development

As aforementioned, the connection will be to an Android phone, therefore Android Studio

was used to develop the app. It is the recommended Android Integrated Development

Environment for developing Android applications. Kotlin or Java were considered as viable

programming languages, but Java was preferred due to its longstanding documentation and

variety of examples. Constraints exist with regards as to which Android API to use, due to

MIDI being supported from Android API 23 (Marshmallow) and above. Android API 29 (Q)

also added MIDI 2.0 functionalities, but Android API 23 is the minimum API that MIDI app

development was feasible [61].

An example provided by the Android Developers [62] was used to aid the application

development . A different Graphical User Interface (GUI) was created as well as a synthesiser

using a sine wave instead of the default saw wave. Variables were also manipulated in specific

ways as to allow the user to change the outputted sound using the SingleTact sensors. Any

specific differences or additions to the original example files are commented with the word

“ADDITIONS”. Application code where the files were changed or modified is shown in

Appendix B2. They are separated in classes for code and functionality organisation.

3.3.1 GUI

The GUI was decided to be as minimalist as possible, as to highlight certain features and so

that the user is not overwhelmed with options. Figure 41 exhibits the ways the app adapts at

the same time the user is interacting with it. The application starts with all checkboxes

unchecked and with the main button and spinner disabled. Once the user selects a sound

and two effects, the button is made active in order for the user to press it and set the options

they have selected. Once the button is pressed, the checkboxes become inactive, the text on

the button changes to “Reset” and the spinner [63] is enabled. The user now can either reset

to go back to the first state and re-check their desired options, or they can select the Arduino

from the spinner and begin playing with the TMC.

3.3.2 Classes: SelectionConfig()

This class was created to store the user configuration, and it allows for better code and

variable organisation. It is a static class, meaning it is only created once, and the values are

overwritten when the appropriate code is called. Variables are declared as “private static”

and getters or setters are used to access or write to these variables. This class allows for the

storing of a Sound ID variable, two Effect ID variables and a boolean Set variable.

Figure 41 Five main states of the app. From top left to bottom right, initial state, sound selection state, effect selection state, set state, playing state. App icon shown in the middle.

These variables reflect the different interactions the user has with the app. It can be viewed

in Appendix B2.1. The different options on the GUI represent different values within the

”SelectionConfig.java” class, as shown in Table 7.

Table 7 Different possible values of the variables in the SelectionConfig.java class. These change based on the selections made by the user.

On GUI | In Application
Sin Wave | sound_id = 1
Saw Wave | sound_id = 2
Pitch | effect_id = 1
Shorter Notes | effect_id = 2
Note Bend Up | effect_id = 3
Note Bend Down | effect_id = 4

3.3.3 Classes: MainActivity.java
Here is the main file where the project then branches off into different functions for different

functionalities; it can be found in Appendix B2.2. The functionality described in the GUI is

achieved using Lines 100 to 227 and Lines 230 to 321 in the MainActivity.java file. These are

the functions that are executed when a checkbox is checked, or when the button is pressed.

3.3.3.1 Imports
Most imports were automatically generated by Android Studio when the code was being

written. The imports for MIDI functionality and the Android Example files were manually

imported.

3.3.3.2 Functions: First Execution and onCreate()

During first execution of this class, there are variable initialisations and the “onCreate()”

function is executed (Lines 24 to 59). This function sets up the initial states of the checkboxes,

button, and spinner. It also checks if MIDI is supported by the device the application is being

run on, and if not then MIDI is not setup and the application does nothing.

3.3.3.3 Functions: Android Example

Lines 62 to 96 are lines used from the Android Example provided. The “setupMIDI()” function

initialises the MIDI connection by getting the device selected from the MIDI spinner, and

connecting to it. The “closeSynthResources()” and “onDestroy()” functions exist to allow the

app to stop outputting gracefully and with no crashing. The “MyPortsConnectedListener()”

function is used to check whether the connection to the selected device is successful or in

error.

3.3.3.4 Functions: onCheckBoxClicked()

When a checkbox is clicked this function is executed. It goes through and checks the state of

each checkbox in the GUI and reacts accordingly when a specific checkbox is checked. For

example, in Lines 114 to 126, it checks which sound checkbox is selected and disables the

other one.

Lines 128 to 213 are similar to the sound checkboxes but more complicated since the user

has to make two choices instead of one. For example, in the if-statement in Lines 130 to 141

a variety of checks occur. It checks if the checkbox is filled and assigns the corresponding

effect value. It also checks if the checkbox is deselected, and the resets the effect value in

the SelectionConfig class.

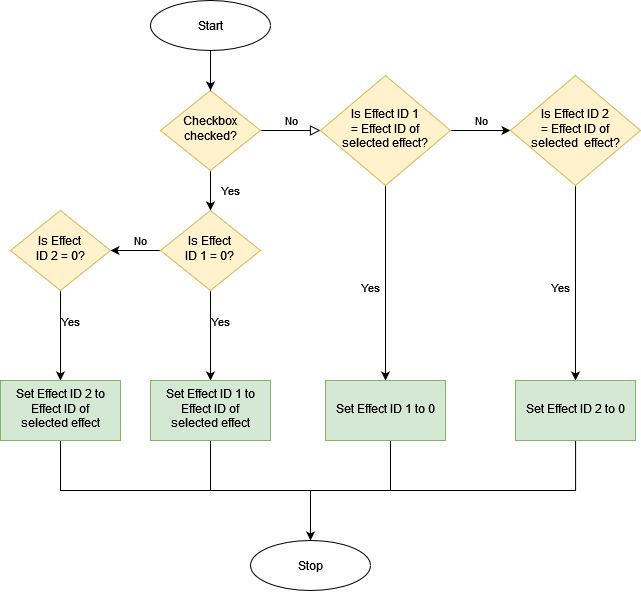
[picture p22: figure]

Figure 42 High level flowchart showing how the effect IDs are assigned. Rectangular boxes are actions and rhombus shapes are checks.

The next section of code in Lines 183 to 212 simply detects which checkboxes have been

selected, and disables the rest. The different combinations of options are shown in Table 4.

This informs the user that no other selections should be done, and that they can press the

set button. To check if all selections are made the “effects_selected” and “sound_selected”

variables are assigned to be true at the correct points in the code. If both are true, then the

user can set their configuration with the toggle button.

Table 8 Showing inactive checkboxes based on selections. Each number is the effect ID of the effect.

Selection 1 | Selection 2 | Inactive
1 | 2 | 3, 4
1 | 3 | 2, 4
1 | 4 | 2, 3
2 | 3 | 1, 4
2 | 4 | 1, 3
3 | 4 | 1, 2

3.3.3.5 Functions: onButtonClicked()

When the button in the app is pressed, this function is executed. Its purpose is to notify the

program that no other selections are to be made and to also show to the user that no other

selections are allowed. This is done by disabling and enabling the correct GUI components.

Moreover, it is used to reset the program to its initial state and let the user start over with

new sound selections, and new effects. Error checking for both of the effect ID variables also

occurs when effects are set. A check is run to see if the variables have the same value in error.

3.3.4 Classes: EnvelopeADSR.java

The ADSR acronym in the name of this class stands for Attack, Decay, Sustain and Release

where each term described affects that aspect of the specific sound [64]. This class was

provided by the Android Example and only had some minor modifications made to it. In

order for the “mSustainLevel” variable to be set and accessed by another class the

“setSustainLevel()” function and the aforementioned variable are set to “static” (Lines 58

to 65 and Line 35 in Appendix B2.3). This allows for the Shorter Notes effect to take place.

3.3.5 Classes: SineVoice.java

The “SineVoice” class is used to create and access a sine wave synthesiser using the

provided “SineOscillator” class. It is different to the provided saw wave synthesiser.

In Figure 43, the wave shapes of both sine and saw waves are shown. Each wave type

requires a different oscillator and both types of oscillator classes are provided [65]. In the

“SineVoice” class, the “SineOscillator” is used in the same way the “SawOscillator” is used

in the “SawVoice” class. Code for the respective classes can be found in Appendix B2.4,

B2.5, B2.6 and B2.7. A sine oscillator and envelope are instantiated and used to create the

synthesiser using the same class methods. This class is used when the user selects the Sine

Wave checkbox in the GUI.

3.3.6 Classes: SynthEngine.java

In “SynthEngine.java” is where MIDI and Synthesiser classes come together and all MIDI

messages are received and executed. The first check that occurs is in Appendix B2.8 Lines

230 to 240, where based on the user’s selection of sound and the received sound ID, the

outputted wave is either a sine wave or a square wave. In Lines 96 to 119 the main switch-

case statement occurs which checks what kind of MIDI event is being received. The cases

that occur in this project are “MidiConstants.STATUS_NOTE_OFF”,

“MidiConstants.STATUS_NOTE_ON” and “MidiConstants.STATUS_CONTROL_CHANGE”.

Figure 43 Examples of different wave shapes. On the top and bottom there is the Sine Waveform and the Saw/Sawtooth

In the case of a Note Off or Note On MIDI message, it is handled by the corresponding

functions provided by the Android Example. The addition to this switch-case statement is

the case where a Control Change is sent by the TMC, in Lines 112 to 115. This handles the

effect values on the outputted sound. As aforementioned in Table 5, the TMC sends Control

Change numbers 7, 12 and 13. These can be mapped to any action through a switch-case

statement, which is how it is done in the “controlChange()” function in Lines 271 to 319.

When the right-most SingleTact which is the Control Change number of 7, sends a MIDI

message, it is reflected by the corresponding code in the case of 7. That CC number and in

turn that SingleTact sensor is used to lower the volume of the outputted sound. This is

done by changing the “velocity_cc” variable in Line 274 by subtracting the received CC

value, and passing it to the “noteOn()” function in Line 101 of the switch-case statement.

The code for CC numbers 13 and 12 in Lines 276 to 319 is the same, so only one section will

be examined. This is because the two SingleTacts send different CC numbers, but both must

be able to interact with all of the effects. It checks which effect ID is selected and then acts

accordingly based on Table 7. All CC values sent are between 0 and 127 to comply with the

MIDI standard.

3.3.6.1 Pitch

The pitch effect is executed in Lines 277 to 282. The “mFrequencyScaler” variable is

manipulated to change the scaling of the note’s frequency. The value of this variable is

passed to the “noteOn()” function in Line 259 and then the next note played will have the

new value.

Frequency Scaler = 1 +

CC Value
16 | (3)

Equation (3) is used to calculate the frequency scaling. Due to the CC value being between 0

and 127 and only setting values above 10, the range of values for the Frequency Scaler will

be 1.625 to 9. Since CC value is an integer (represented by the “controlValue” variable) it is

truncated each time the calculation is executed.

Frequency scaling allows for a greater range for the TMC. When multiplying the frequency

by an integer number, another note is played corresponding to that frequency [66]. For

example when multiplying the note C2 by 2, the note C3 is reached and when multiplying

by 3 then the note G3 is reached.

3.3.6.2 Shorter Notes

For the Shorter Notes effect, a function in the EnvelopeADSR class was set to “public static”

in order to allow for access in the SynthEngine class. This was discussed in section 3.3.3. The

value for the “setSustainLevel()” function in Line 286 is calculated and stored in Line 285 in

the “changeSustain” variable.

Cℎange Sustain =

CC Value
256 | (4)

The variable is changed using Equation (4) and with only accepting CC values above 10, it

allows for values between 0.039 and 0.496. This range is acceptable due to the default

value of 0.3.

3.3.6.3 Pitch Bend Up & Pitch Bend Down

Both of these effects use the same ideas and functions. The “pitchBend()” function is used

for both. The “map()” function from the Arduino Reference [60] is also implemented into the

application in Lines 321 to 324. It allows for easier calibration of the CC value inputs so that

they are within MIDI standard.

The way pitch bending occurs within the app is uncommon within the MIDI standard, but

shows the flexibility of the MIDI Control Change Messages. A pitch bend is executed in Lines

310 to 314 when the effect is selected from the GUI and a CC number of 12 or 13 occurs. In

traditional MIDI messages, a separate Pitch Bend message exists with its own Event Value

which is different to the method used in the app. However, in both cases the “pitchBend()”

function is used for the pitch bend effect.

For the Pitch Bend Up effect, a value between 8192 and 16384 is required. For the Pitch Bend

Down effect, a value between 0 and 8192 is needed instead. The value of 8192 means no

pitch bend will happen to the current note [67].

This is different than from pitching up the note using frequency scaling in the Pitch effect.

The pitch bend effect can reach notes that are not within any Western scale, whereas the

Pitch effect simply multiplies the note frequency to change the note played.

3.3.7 AndroidManifest.xml

The Android Manifest file is an automatically generated file, but some manual additions were

required in order for the application to work. In Appendix B2.9, Line 14 was changed to use

the custom icon for the application. Lines 31 to 41 were required in order for the application

to run and were referenced from the Android Example library.

3.3.8 Android Example Classes

From the referenced Android Example [62], the only files changed were EnvelopeADSR,

SineVoice, SynthEngine, AndroidManifest, activity_main.xml (the GUI) and MainActivyty. The

rest are as downloaded from the example. The same directory and file structure was used as

to eliminate unnecessary file directory changes within the code.

3.3.9 Other Files

All files that are not discussed in this report are automatically generated or made with

Android Studio Tools (eg. app icon) and therefore will not be mentioned.

### 3.4 Software Development Alternatives

There are a variety of alternatives for application development. One alternative was using

MIT App Inventor [68], but more control was required for each function executed so a lower

level approach was preferred. JUCE [69] could also have been used for creating an application

with MIDI functionality, but due to the Android Example it was not chosen as the preferred

method. Another example by Mobileer [70] could also have been used but it was noticed

that it had nearly identical code to the Android Example. Therefore due to the example being

provided by Android themselves, their example was preferred.

### 3.5 Software Development Issues

Multiple issues arose during software development. The two major ones were issues with

the Arduino MIDI library and issues with application code execution. Initially, the library for

USB and MIDI functionality used was MIDIUSB [71], but there were issues with detecting

MIDI events on an Android device. Multiple tests with different USB cables, different MIDI

devices, and different Android phones were conducted, with the conclusion being that the

Arduino code was the issue. The library was then changed to the USB-MIDI library that is

currently used in the project.

It was noted that when code was added or commented out, the app would not run the code.

After getting some assistance with Java from an experienced Computer Science professor, it

was discovered that there were duplicate files and that the project was falling back on those

files when building. Furthermore, it was found that the app fell back on the Android Example

application that was built, and ignored its own code. The app was then debugged with no

other apps installed, which fixed the issue.

### 3.6 Flowchart

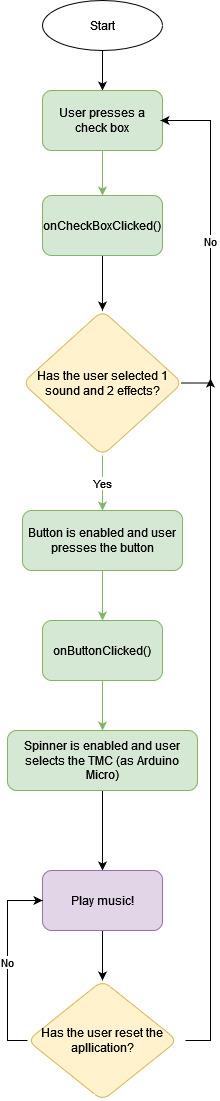
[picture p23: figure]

Figure 44 High level flowchart of app functionality. Rectangular boxes are actions and rhombus shapes are checks.

## 4.0 Chapter IV – Testing and Results

### 4.1 Hardware Testing

Hardware was tested using the Arduino IDE and by checking the output. During the tests with

test code H2 and H5, the “testSensorOutputs()” was used (in Lines 174 to 190 in Appendix

B1.1). The variables used are based on the component(s) being tested and the function is

placed at Line 65.

Table 9 Hardware testing outcomes. Test code used to refer to the tests.

Test Code | Test | Method | Expected Outcome | Observed Outcome | Comments
H1 | Arduino Micro being able to load code. | Connecting to Arduino IDE and outputting the string “test” on the Serial Monitor. | Outputted “test” on serial monitor. | Outputted “test” on serial monitor. | Test passed.
H2 | HC-SR04 outputting a correct measured distance. | Using the “testSensorOutputs()” and “getDistance()” functions with the “dist” variable while checking the output on the Serial Monitor. A ruler was used to check distance measurement output and hand was positioned at 30 cm. | If hand placed at 30 cm then the value outputted should be 25 cm due to the offset. | 25 cm on average but with noise values ranged from 23 to 28 cm. | Test passed. No averaging was used for this test.
H3 | SingleTact sensor (individual). | Using the provided “SingleTactDemo.ino” [72] and reading the output on the Serial Monitor. | Values from 256 to 1024. | Values from 256 to 1022 and two sensors have a minimum value of 260. | Test passed. Range was adjusted in code so that all three have identical outputs.

Table 10 Second table for hardware testing outcomes.

Test Code | Test | Method | Expected Outcome | Observed Outcome | Comments
H4 | SingleTact sensor (all three). | Using the provided multi-sensor demo [73] and modifying it for three sensors instead of two. | Same results as the previous test, but all outputted at the same time on the Serial Monitor. | All readings outputted and inspected on serial monitor. | Test passed.
H5 | All four sensors together can provide a measurement simultaneously. | Using all sensor measurement variables (Lines 26 to 30) and the “testSensorOutput()” function. | All previous sensor results outputted on the serial monitor at the same time. | All outputs on the Serial Monitor. | Test passed.

Figure 45 Output on Serial Monitor of Arduino IDE with all four sensors. Displays the output of H5 which also encompasses the H1 to H4 test codes

### 4.2 Software Testing

Testing for the software was carried out while connected to the TMC app (in Tests S1, S2, S7

and S8). The MIDI message detection on the PC was done using MidiView [74] and on Android

it was done using MIDI Scope [75]. Notes with a number next to the note name (eg. C3 and

C4) indicates the same note but in different octaves. The different states of the app are listed

and displayed in Figure 41.

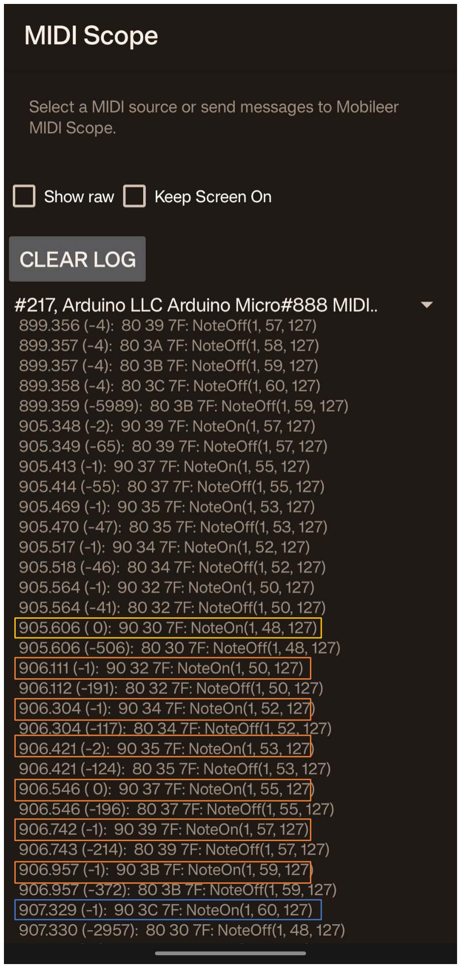
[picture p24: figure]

Figure 46 MIDI note output detection. Yellow box highlights the minimum note and blue highlights the maximum note. In orange are the rest of the notes outputted by the “noteOut_Cmaj()” function.

4.2.1 Microcontroller Code Testing

Table 11 Microcontroller code testing.

Test Code | Test | Method | Expected Outcome | Observed Outcome | Comments
S1 | TMC stays idle when not in use. | Hand over the HC-SR04 for 5 seconds to get sensor measurements. Then removed and waited for TMC to be idle. | TMC shuts off. | TMC shuts off. | Test passed.
S2 | TMC does not exceed maximum note or goes below the minimum note. | Using MidiView and looking at the maximum and minimum outputted notes. | Notes C3 and C4. | Note C3 and C4. | Test passed.
S3 | MIDI Note On message sent. | Check on MidiView for the note on message. | MIDI Note On. | MIDI Note On. | Test passed.
S4 | MIDI Note Off message sent. | Check on MidiView for the note off message. | MIDI Note Off. | MIDI Note Off. | Test passed.
S5 | MIDI Control Change message (numbers 7, 12 and 13) sent independently of the distance measurements. | Check on MidiView for the different control change messages. | MIDI Control Change with values 7, 12 and 13. | MIDI Control Change with values 7, 12 and 13. | Test passed.
S6 | All MIDI messages can be observed on an Android device. | Check on MIDI Scope for all the aforementioned messages. | All MIDI messages used are observed. | All MIDI messages used are observed. | Test passed.

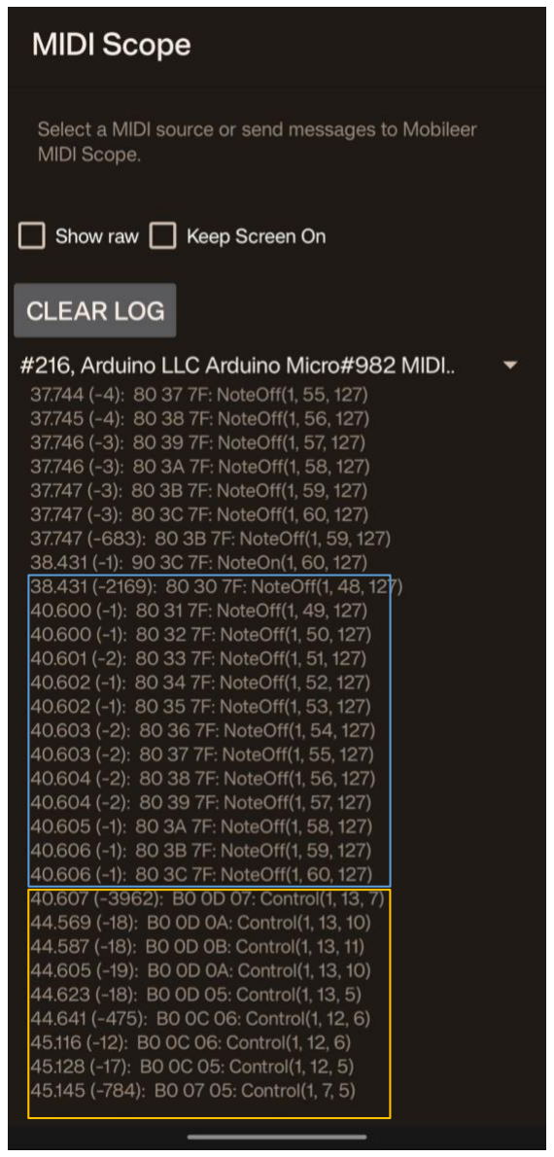
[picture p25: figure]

Figure 46 shows the outputs of the “noteOut()” function (Appendix B1.1 Lines 222 to 240)

which has the output discussed in Section 3.2.5. Therefore, by interpreting the results in

Figure 46 and Figure 47, results of tests with test code S1 to S6 are shown.

Figure 47 MIDI outputs of the CC messages. Highlighted in yellow are the 7, 12 and 13 MIDI CC numbers sent. In blue is the code executed when the TMC turns off and is

4.2.2 Application Testing

Table 12 Application testing outcomes.

Test Code | Test | Method | Expected Outcome | Observed Outcome | Comments
A1 | App starts at the correct initial state | Open the app | Initial State | Initial State | Test passed.
A2 | Correct check boxes become disabled based on the configuration | Using Table 8, and checking which ones are greyed out. | The entries in Table 8 are true. | The entries in Table 8 are true. | Test passed.
A3 | “Set” button becomes enabled when all choices are made | Select one sound and two effects. | The button is enabled. | The button is enabled. | Test passed.
A4 | “Reset” resets the choices | Pressing the reset button once in the set or playing states. | App completely resets. | App completely resets. | Test passed.
A5 | The spinner correctly connects and disconnects a MIDI device | Selecting and deselecting the MIDI device on the spinner and observing the outputted message on the GUI. | App correctly connects and disconnects the TMC when selected. “Device Connected” appears as a Toast [76] output. | App correctly connects and disconnects the TMC when selected. “Device connected” appears. | Test passed.

Table 13 Second table for application testing outcomes.

Test Code | Test | Method | Expected Outcome | Observed Outcome | Comments
A6 | App outputs a note for each option possibility. | Use all possible options in Table 8 for both Saw and Sine wave configurations. | App interacts with all effects and configurations. | App interacts with all effects and configurations. | Test passed.
A7 | Right-most sensor turns down the volume of the note played | Press sensor while playing with the TMC. | Volume turns down. | Volume turns down. | Test passed.

Outcomes of tests A1 to A5 are shown in “tests A1 to A5.mp4” either in the provided

supplemental material or on the GitHub page under the “Images and Videos” folder. The

files “saw wave outputs.mp4” and “sin wave outputs.mp4” show the outcomes of tests A6

and A7, also found in the same folder.

### 4.3 Results

Video files mentioned are provided in the “Images and Videos” folder.

Table 14 Results for the project objectives. Objective code for easier reference.

Objective Code | Objective Description | Result
O1 | Theremin hardware interface using an ultrasonic transmitter and receiver. | Figure 45 shows some outputs of the HC-SR04 for hand measurements. In video “singletact and app interaction results.MOV” the right-most SingleTact is used for the volume change.
O2 | Allow instrument to send MIDI commands in order for it to be used in other applications. | Figure 46 and Figure 47 show the listed MIDI commands in Table 5 being sent and detected. In the video named “DAW MIDI compatibility.mp4”, the versatility of the TMC is shown by mapping the SingleTacts to a filter of a digital synthesiser in a DAW. Achieved using FL Studio [77].
O3 | Application created to provide phone interaction with instrument. | The files “saw wave outputs.mp4” and “sin wave outputs.mp4” show how the app interacts with the inputted instrument data.
O4 | Implement three SingleTact sensors, two of which are for effects. | Interaction of all three SingleTact sensors (two for effects and one for volume) is shown in the video file named “singletact and app interaction results.MOV”.
O5 | Ability to play a simple song like “Amazing Grace”. | Files named “amazing grace take X.mp4” where X is numbers 1 to 5, show different takes of this result. Figure 48 shows a MIDI record of the melody being played.

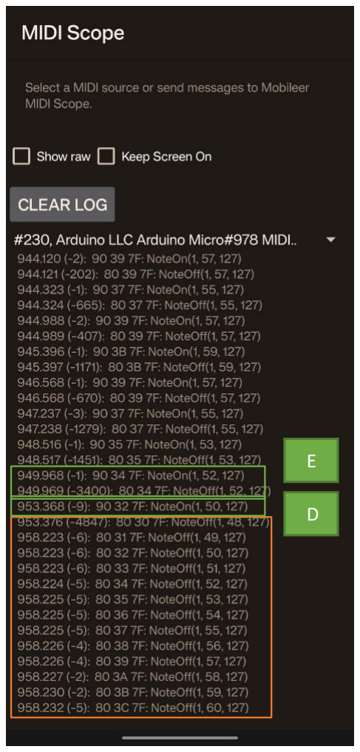
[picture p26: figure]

Figure 48 MIDI records of playing a melody like "Amazing Grace". Notes in green boxes are the notes for the start of the Amazing Grace melody, which are in order D G B G B A G E D. The final orange box is the TMC becoming idle.

## 5.0 Chapter V – Evaluation

### 5.1 Discussion

Table 14 demonstrates the different results obtained for each objective. For objective with

code O1, the final product can behave as a Theremin with the HC-SR04 transceiver/receiver

measuring the hand distances. The volume change is achieved with the right-most SingleTact

being mapped solely to the volume of the next note. This fulfils the theremin requirements,

however the chosen ultrasonic sensor is not very accurate when it comes to measuring hand

distances, given the fact that hands are a soft, irregular surface, and the noise from the wave

reflections in the room was also picked up by the sensor. To remedy this, an averaging

method was used as discussed in Section 2.4, but this removed the ability to pinpoint specific

notes in the range of the TMC. For example, in the final product the ability to instantly play a

note in any part of the scale is not possible, because the averaging method used to remove

the noise, forced the product to always work in a sequential manner. This does remove some

objectively musical capabilities of the TMC, but due to the subjective experience of music, it

can be considered a unique feature of the product. Even though objective O5 was completed,

it had difficulties being fulfilled because of this reason as well. The TMC can reach all of the

required notes, but practice was required to compensate for the inaccuracies of the HC-SR04,

making the project a difficult instrument to learn.

For objective O2, the TMC can be mapped to different controls in a DAW as discussed, so it

can be used effectively as a General MIDI controller. Other applications such as the ones used

in testing, as well as the companion app, can also detect the MIDI commands being sent so

it is compatible with all MIDI compatible applications. The SingleTacts can also be used to

send MIDI CC messages (numbers 7, 12 and 13) while no notes are being played, therefore

the TMC can also be used as a MIDI effect controller while another controller is being played.

For instance, the SingleTacts can be mapped to a virtual knob to change a certain value which

can be controlled by another person separately. Another person could then be playing a

keyboard MIDI controller and both of them could play music together; each person could

change what the other hears using their controllers. An issue with the current set of

commands being sent is that they are mapped for specific use in the app, so other for other

apps would have to map the current MIDI Control Change commands to other actions. If the

app connected to the TMC has no mapping compatibilities, the SingleTacts may have

unpredictable behaviour such as changing random options or no effect at all. This depends

on the individual app being examined.

The application created fully satisfies objective O3. The app is a fully customised application

made specifically for the TMC. It allows for customisation of the sound output as well as the

selection of which effects can be used at a time on the corresponding sound. Other MIDI

controllers can be used with the app due to it being MIDI compatible, but their function is

reliant on which MIDI commands they are able to send. If they can send the commands in

Table 5, then the app can be used as designed.

The three SingleTact sensors are fully integrated with the TMC allowing for effect

manipulation, assignment as well as volume change of the notes played. This fulfils objective

O4, however the “Pitch” and “Shorter Notes” effects are only executed at the next note being

played. This is also true for the SingleTact sensor assigned to the note volume. Minor

confusion can occur while playing, since it is more common to want to control what is

currently being played rather than the next note the player has in mind. With practice this

can be compensated for, allowing for smoother note transitions while using the volume

sensor as well as the two selected effects.

The general playability of the TMC is an interesting point of discussion. The theremin is

notoriously a difficult instrument to start playing ([78] [79] [80]) and to become proficient in.

This is mainly due to there not being any instant feedback with which note the user is playing.

On a guitar, a player can easily tell what note is being played based on the fret, but since the

theremin is a fretless instrument, it is very easy to play out of tune notes and get lost. This is

the same case with the TMC since it uses the same concepts as the theremin for music

creation. One hand creates the pitch, and the other can control the volume or other effects.

The same difficulty level applies to the TMC although in a different way due to it being tuned

to the C major scale. The user requires practice to find where the different notes are placed

vertically on top of the TMC but there is no need to have a near-pitch perfect ear to find the

notes. The user also has to get used to the way notes are outputted sequentially and with

the audible latency required to calculate the average each time. Coordination of the hands is

also still required to use the effects and volume in a musical manner. Therefore, the TMC can

be considered an introductory and beginner instrument to the theremin family due to it being

tuned, but still having most of the theremin characteristics and difficulties. It is playable the

same ways as a theremin since it has very similar concepts and behaviour.

The TMC along with its companion app is very versatile once closely examined. It can output

two types of sound wave shapes (sine and saw) and use four effects for each one. The effects

provide a range spanning multiple octaves due to the “Pitch” effect. The “Note Bend Up” and

“Note Bend Down” effects allow for it to reach out of tune notes, making the instrument

sound more interesting and less robotic. The “Shorter Notes” effect allow for the TMC to be

used in a more subtle way and when using the “Pitch” effect at the same time, it can provide

some entertaining sounds. The type of music outputted by the TMC can be used in all kinds

of music, but particularly in electronic music. It can provide a unique voice never heard before

due to its one-of-a-kind interface and effect selection. Ambient music has historically used

theremins for a more sci-fi texture, thus making the TMC useable for that as well. Due to

DAWs and the TMC being MIDI compatible, the sounds can be edited and manipulated in

unimaginable ways thus making the final product nearly limitless.

Portability is definitely an advantage of the TMC over other theremins on the market. Since

it is a MIDI Controller, very few analogue or mechanical components are required in order

for it to function, thus making it portable and useable in a variety of spaces. The casing and

the sensor cover also allow protection of the components, but the plastic is somewhat weak

and can break when under heavy weight. Sensor cover can however be lost since it is not

attached to the casing in any way. It also has the advantage of a minimal and quick set-up as

shown in the User Guide in Appendix C.

Safety is a concern for a final product out on the market. The TMC has some security hazards

such as the top lid being opened with some force. This does allow for appreciation of the

inner workings, but the wires and solder joints are exposed to being accidentally touched.

Even though the maximum current and voltage (50 mA and 5 V) of the Arduino Micro is not

lethal or harmful, it should be considered as an issue.

### 5.2 Conclusion

To conclude, this report described the creation of a phone-based tactile musical instrument.

A theremin hardware interface was created using an HC-SR04 ultrasonic receiver/transmitter

to measure the user’s hand movements, as well as a SingleTact sensor used to change the

volume. The final product can send MIDI messages which can be universally interpreted by

MIDI compatible apps and DAWs. The MIDI compatible companion application created can

also be used to interact with the TMC and change the sound output by modifying the sound

and effect settings. Two of the three SingleTacts can be used for effects, with each being

mapped to one of the four effects provided by the companion application. Using the

application or any other MIDI app, the TMC can play a simple melody like “Amazing Grace”

with some practice so that the mechanics of the product become more familiar.

The project started with initial market research to find gaps that could be used to inspire new

solutions. The theremin was observed to have not been used in the phone-based musical

instrument market, and with also observing the popularity of MIDI controllers - a Theremin

MIDI Controller was proposed. Based on that, components and concepts were thought out

and therefore materialised as the project continued. Four 3D prints were made before

deciding on the final one with another one being planned, but other project objectives took

priority. An Arduino Micro was used with three SingleTact sensors and an HC-SR04 ultrasonic

transmitter/receiver to accomplish the proposed project. MIDI functionality was

accomplished using an Arduino library. The companion app was developed using the Java

language and modified examples provided by the Android Developers. A custom GUI was

created to allow unique interaction between the capabilities of the app and the user.

Difficulties with 3D CAD design, Java coding and MIDI library compatibilities were the main

obstacles for the project, due to a lack of knowledge and experience. Issues were dealt with

as they occurred and possible alternatives were planned at each stage. The final product from

this project is a unique take on the MIDI Controller that does not exist on the market

currently. It has near limitless creative possibilities and applications, while also completing

all listed objectives. Therefore, it safe to conclude that the project is a success.

### 5.3 Further Work

A variety of features could have been added on if extra time was provided, but other project

objectives took priority. A separate section of the app could be used to allow for

customisation of the effects. For example, the pitch bend effect could be set to bend only

half an octave. On the main app page or on a separate page, the current note played could

also be displayed to aid the player visually. More effects could have been implemented by

manipulating the oscillators provided; new oscillators could have also been created, such as

a square wave to provide more customisability to the sound.

Currently in the microcontroller code, there are the “pitchBend_mode” and “pitchBend_val”

variables, as well as Lines 80 to 93 in Appendix B1.1. When executed, these provide a

different sounding experience that mimics a real life theremin. However, due to not allowing

the user to change this value, the lines mentioned are not used. Therefore, a potential

addition would have been a switch connecting the Arduino Micro ADC and ground pins. This

would allow the user to select different modes for the TMC.

Some additions to the casing would be an indicator LED to provide confidence to the user

that the TMC is working as it should. A screw could also have been put in place on the top lid

to further prevent unwanted access to the wiring and for added safety. Some ideas

considered for external additions were a guide delineating to the user how to practice the

instrument with more ease; this could take the form of a piece of cardboard with note

markings which the user could place next to the TMC while playing.
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

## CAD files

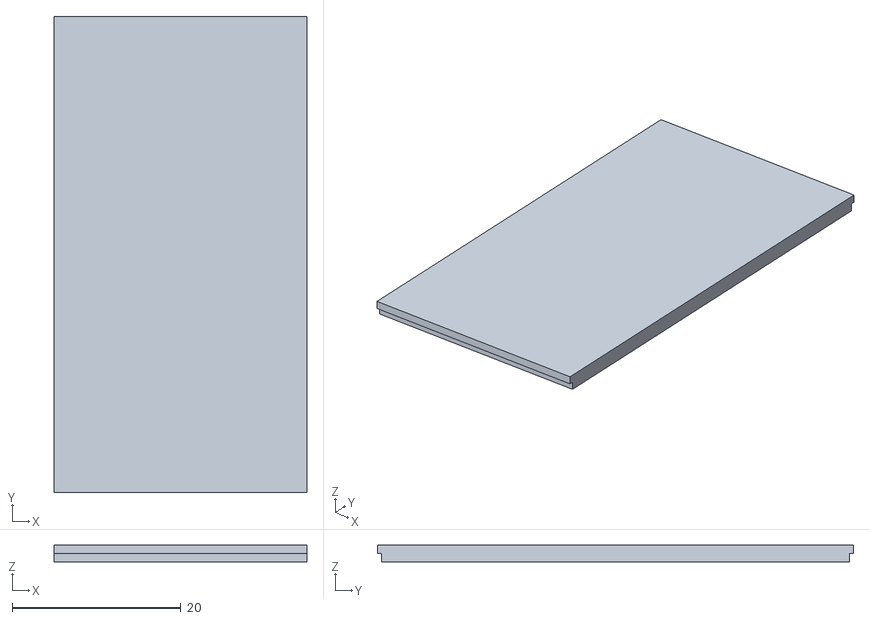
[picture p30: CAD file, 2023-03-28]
3D Prints/print 1 23.11/TMC sensor shelf at front.stl
30.0 x 56.5 x 2.00

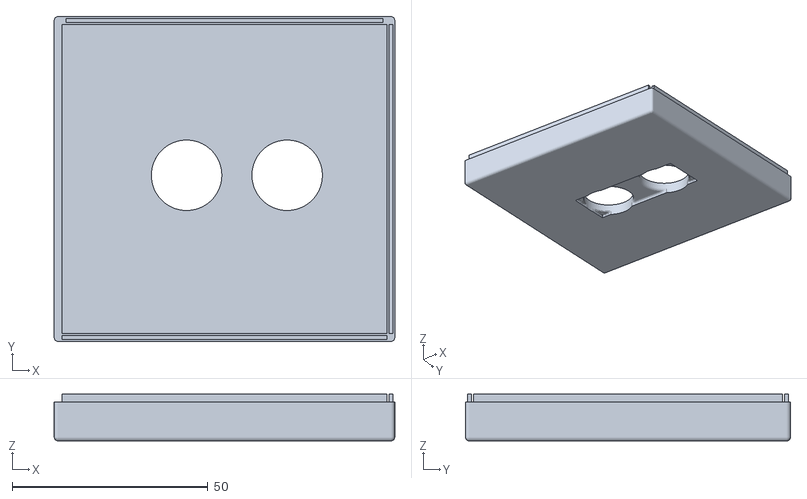
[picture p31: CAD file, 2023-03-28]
3D Prints/print 2 27.11/TMC top lid.stl
87.0 x 83.0 x 12.0

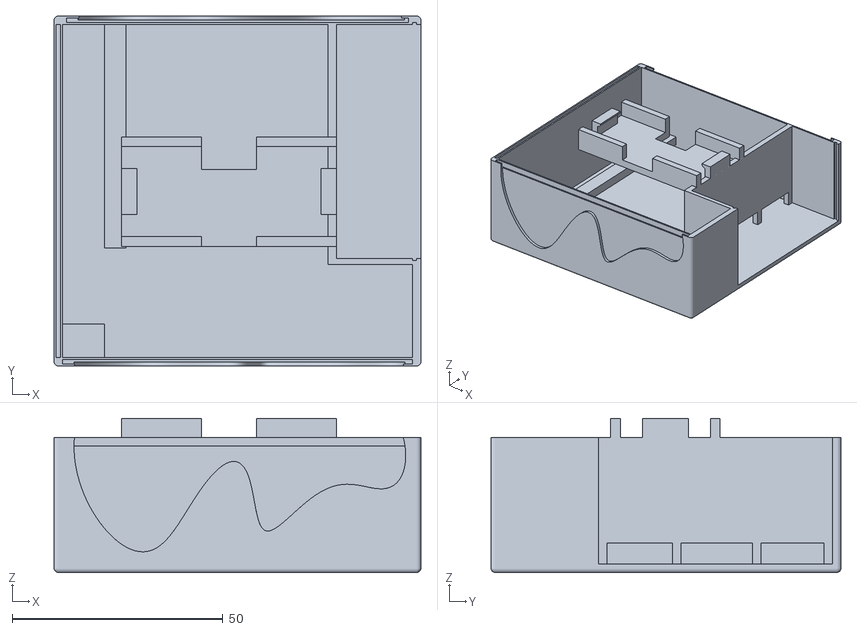
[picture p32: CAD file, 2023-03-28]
3D Prints/print 3 30.11/TMC walls.stl
87.0 x 83.0 x 36.5

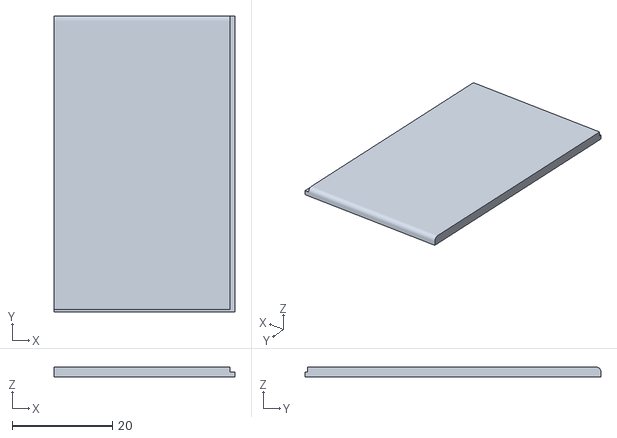
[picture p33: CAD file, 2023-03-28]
3D Prints/print 4 23.12/TMC sensor cover.stl
36.0 x 59.0 x 2.00

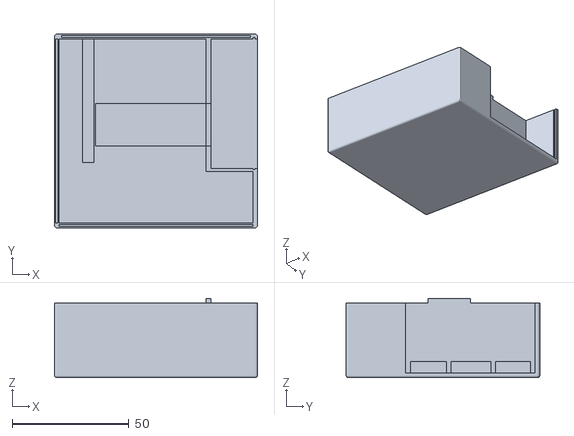
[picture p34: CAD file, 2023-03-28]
3D Prints/print 2 27.11/TMC bottom part.stl
87.0 x 83.0 x 34.0

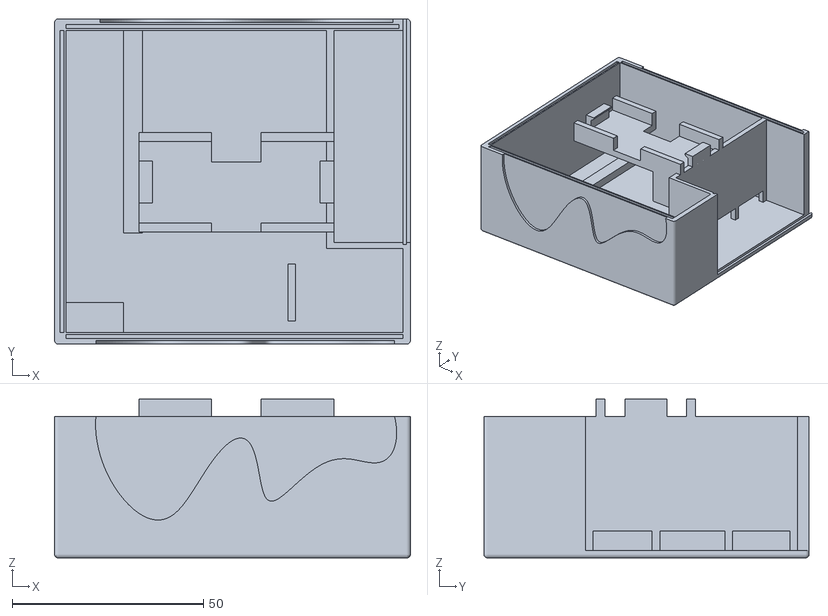
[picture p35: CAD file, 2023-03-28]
3D Prints/print 4 23.12/TMC bottom.stl
93.0 x 85.0 x 41.5

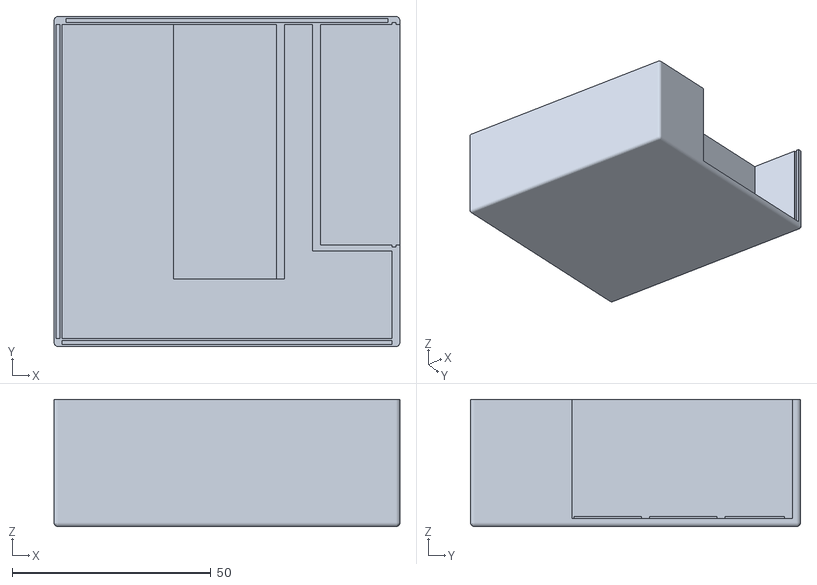
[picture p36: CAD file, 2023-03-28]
3D Prints/print 1 23.11/TMC bottom part.stl
87.0 x 83.0 x 32.0

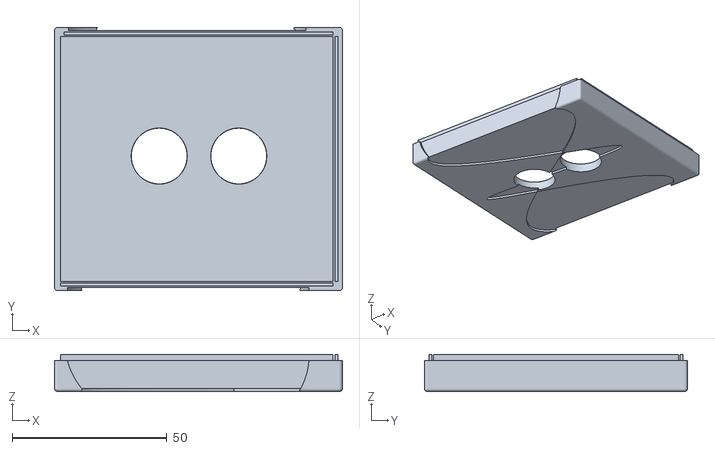
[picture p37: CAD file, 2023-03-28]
3D Prints/print 4 23.12/TMC lid.stl
93.0 x 85.0 x 12.0

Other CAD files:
3D Prints/print 1 23.11/TMC top lid.stl
3D Prints/print 3 30.11/TMC top.stl
3D Prints/print 2 27.11/TMC sensor cover.stl

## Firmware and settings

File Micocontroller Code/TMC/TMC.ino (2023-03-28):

#include <Wire.h>  //For I2C/SMBus
#include <USB-MIDI.h> //Library for sending MIDI messages

USBMIDI_CREATE_DEFAULT_INSTANCE(); //required line to initialise MIDI communication

#define pinEcho 18 //Pin 18 on the Arduino Micro
#define pinTrig 19 //Pin 19 on the Arduino Micro, both used for the HC-SR04

#define range_cm 4 //range of each note
#define max_dist 8 * range_cm - 1  //max distance used = max note played, max_dist * 8 for white keys and max_dist * 13 for white + black keys
#define distance_offset 5 //offset for the initial reading of HC-SR04

#define buffer_size 50 //size of array buffer for the rolling average

#define sensor1_address 0x06  // Peripheral addresses used for SingleTact (SingleTact), default 0x04
#define sensor2_address 0x08
#define sensor3_address 0x0A

//the control change values that each SingleTact sensor will send
#define ST_left_CC 13
#define ST_middle_CC 12
#define ST_right_CC 7

#define enable_pitch_bend 0 //a future setting for only producing bended notes for a more Theremin like experience

//sensor measurements
int dist = 0;
short data1 = 0;
short data2 = 0;
short data3 = 0;

//checks and limits
int buffer[buffer_size] = { 0 }; //initialise an array of size buffer_size
int avg_dist = 0;
int weighted_avg_dist = 0;

//note data
int prev_note = 0;
int curr_note = 0;
int velocity = 0;

//for turning on or off the TMC based on input
char idle = 0;
bool on = true;

//customisations
int pitchBend_mode = enable_pitch_bend;
int pitchBend_val = 0;

//function initialisations
int* popBuffer(int data, int buffer[buffer_size]);
int calcAvg(int buffer[buffer_size]);

void setup() {
  setupUSR();
  MIDI.begin(1); //begin MIDI on channel 1
  Wire.begin();  // join i2c bus (address optional for master)
  Serial.begin(31250);  //serial for output, 31250 for correct MIDI output
  Serial.flush(); //waits for the transmission of outgoing serial data to complete
}

void loop() {

  measureAndCCsend();

  if (dist < max_dist) { //enter only if the measured distance is less than the max distance
    idle = 0;  //idle state set to false to signify it is working
    on = true; 

    avg_dist = calcAvg(popBuffer(dist, buffer)); //calculate the average distance
    weighted_avg_dist = (1.0 * avg_dist) + (0.0 * dist); //calculate the weighted distance

    curr_note = noteOut_Cmaj(weighted_avg_dist); //set the current note to be the value of the noteOut function with the weighted average distance

    if (curr_note != prev_note && curr_note > 20 && pitchBend_mode == 0) {  //>20 is to prevent other random notes occuring when the variables are empty

      MIDI.sendNoteOff(prev_note, 127, 1); //turn off the previous note
      MIDI.sendNoteOn(curr_note, 127, 1); //send the current note

    } else if (pitchBend_mode == 1) { //code only executes if pitch bend mode is enabled but no functionality is provided to the user

      MIDI.sendNoteOff(prev_note, 127, 1); //do the same thing as before but 
      curr_note = 48; //always set the current note to be number 48
      MIDI.sendNoteOn(curr_note, 127, 1);

      pitchBend_mode = 2; //set to 2 so that only pitch bend values get sent in the next iteration

    } else if (pitchBend_mode == 2) {

      pitchBend_val = map(weighted_avg_dist, 0, max_dist, MIDI_PITCHBEND_MIN, MIDI_PITCHBEND_MAX); ////use the map function to map the weighted distance between 0 to 16383

      MIDI.sendPitchBend(pitchBend_val, 1); //send the pitch bend value
    }
    prev_note = curr_note;  //gets stored before and after each check
  } else if (on) {          //if the distance is way too big it means no hand on top of USR
    idle++; //idle counter gets iterated
    if (idle > 100) { //if it reaches 100 
      reset(); //reset the TMC
      pitchBend_mode = enable_pitch_bend; //reset the pitch bend value to default
    }
  }
}

void setupUSR() { //function to set up the connections to the HC-SR04
  pinMode(pinEcho, INPUT); //set pin 18 to be an input pin
  pinMode(pinTrig, OUTPUT); //set pin 19 to be an output pin
}

int getDistance() { //function to measure distance using HC-SR)4
  int _dist = 0;
  digitalWrite(pinTrig, LOW);  //give a short low pulse to have a cleaner high pulse
  delayMicroseconds(2);
  digitalWrite(pinTrig, HIGH);
  delayMicroseconds(10);       //give 10 us high pulse on the trigger pin
  digitalWrite(pinTrig, LOW);  //reset to low

  //speed of sound is 343 m/s so it is 0.0343 cm/us, divided by 2 to find distance,
  _dist = (pulseIn(pinEcho, HIGH) * 0.0343) / 2.0;  //function returns microseconds

  _dist -= distance_offset; //subtract the distance offset to achieve the lowest measurement of 0
  if (_dist < 0) { _dist = 0; } //if it goes below 0 then set it to 0


  return _dist; 
}

short readDataFromSensor(short address) { //function to read data from SingleTact sensors
  int i2cPacketLength = 6;    //i2c packet length. Just need 6 bytes from each slave
  byte outgoingI2CBuffer[3];  //outgoing array buffer
  byte incomingI2CBuffer[6];  //incoming array buffer

  outgoingI2CBuffer[0] = 0x01;             //I2c read command
  outgoingI2CBuffer[1] = 128;              //Slave data offset
  outgoingI2CBuffer[2] = i2cPacketLength;  //require 6 bytes

  Wire.beginTransmission(address);             // transmit to device
  Wire.write(outgoingI2CBuffer, 3);            // send out command
  byte error = Wire.endTransmission();         // stop transmitting and check slave status
  if (error != 0) return -1;                   //if slave not exists or has error, return -1
  Wire.requestFrom(address, i2cPacketLength);  //require 6 bytes from slave

  byte incomeCount = 0;
  while (incomeCount < i2cPacketLength)  // slave may send less than requested
  {
    if (Wire.available()) {
      incomingI2CBuffer[incomeCount] = Wire.read();  // receive a byte as character
      incomeCount++;
    } else {
      delayMicroseconds(10);  //Wait 10us
    }
  }

  short rawData = (incomingI2CBuffer[4] << 8) + incomingI2CBuffer[5];  //get the raw data

  //used for debugging
  // Serial.println("Index 0:");
  // Serial.println(incomingI2CBuffer[0]);
  // Serial.println("Index 1:");
  // Serial.println(incomingI2CBuffer[1]);
  // Serial.println("Index 2:");
  // Serial.println(incomingI2CBuffer[2]);
  // Serial.println("Index 3:");
  // Serial.println(incomingI2CBuffer[3]);
  // Serial.println("Index 4:");
  // Serial.println(incomingI2CBuffer[4]);
  // Serial.println("Index 5:");
  // Serial.println(incomingI2CBuffer[5]);
  // Serial.println("\n");
  //Serial.println(rawData);

  return rawData;
}

void testSensorOutputs(int dist, short data1, short data2, short data3) { //function to give sensor outputs in Arduino IDE
  Serial.print("HC-SR04 Data:"); 
  Serial.print(dist); //output the corresponding variable with the correct label
  Serial.print("cm\n");

  Serial.print("I2C Sensor 1 Data:");
  Serial.print(data1);
  Serial.print("\n");

  Serial.print("I2C Sensor 2 Data:");
  Serial.print(data2);
  Serial.print("\n");

  Serial.print("I2C Sensor 3 Data:");
  Serial.print(data3);
  Serial.print("\n");
}

int noteOut(int dist) { //function that outputs the MIDI note value based on the distance measured
  if (dist <= range_cm * 0 && dist <= (1 * range_cm) - 1) { //range variable is used here to calculate the space each note will take
    return 48;  //C4
  } else if (dist <= range_cm * 1 && dist <= (2 * range_cm) - 1) {
    return 49;  //C#4
  } else if (dist <= range_cm * 2 && dist <= (3 * range_cm) - 1) {
    return 50;  //D4
  } else if (dist <= range_cm * 3 && dist <= (4 * range_cm) - 1) {
    return 51;  //D#4
  } else if (dist <= range_cm * 4 && dist <= (5 * range_cm) - 1) {
    return 52;  //E4
  } else if (dist <= range_cm * 5 && dist <= (6 * range_cm) - 1) {
    return 53;  //F4
  } else if (dist <= range_cm * 6 && dist <= (7 * range_cm) - 1) {
    return 54;  //F#4
  } else if (dist <= range_cm * 7 && dist <= (8 * range_cm) - 1) {
    return 55;  //G4
  } else if (dist <= range_cm * 8 && dist <= (9 * range_cm) - 1) {
    return 56;  //G#4
  } else if (dist <= range_cm * 9 && dist <= (10 * range_cm) - 1) {
    return 57;  //A4
  } else if (dist <= range_cm * 10 && dist <= (11 * range_cm) - 1) {
    return 58;  //A#4
  } else if (dist <= range_cm * 11 && dist <= (12 * range_cm) - 1) {
    return 59;  //B4
  } else if (dist <= range_cm * 12 && dist <= (13 * range_cm) - 1) {
    return 60;  //C5
  }
}

int noteOut_Cmaj(int dist) { //same as the noteOut function but here it is tuned to play C major
  if (dist <= range_cm * 0 && dist <= (1 * range_cm) - 1) {
    return 48;  //C3
  } else if (dist <= range_cm * 1 && dist <= (2 * range_cm) - 1) {
    return 50;  //D3
  } else if (dist <= range_cm * 2 && dist <= (3 * range_cm) - 1) {
    return 52;  //E3
  } else if (dist <= range_cm * 3 && dist <= (4 * range_cm) - 1) {
    return 53;  //F3
  } else if (dist <= range_cm * 4 && dist <= (5 * range_cm) - 1) {
    return 55;  //G3
  } else if (dist <= range_cm * 5 && dist <= (6 * range_cm) - 1) {
    return 57;  //A3
  } else if (dist <= range_cm * 6 && dist <= (7 * range_cm) - 1) {
    return 59;  //B3
  } else if (dist <= range_cm * 7 && dist < (8 * range_cm) - 1) {
    return 60;  //C4
  }
}

int* popBuffer(int data, int buffer[buffer_size]) { //function to populate the buffer array one value at a time
  for (int i = buffer_size - 1; i > 0; i--) {
    buffer[i] = buffer[i - 1]; //shift the value in index i, one to the right
  }
  buffer[0] = data; //assign the new data to the first value
  return buffer;
}

int calcAvg(int buffer[buffer_size]) { //calculate the average by taking the buffer array as an input
  int total = 0; //initialise the total to be 0
  for (int i = 0; i < buffer_size; i++) {
    total += buffer[i]; //add each value in the array to the total
  }
  return total / buffer_size; //divide by the buffer size to get the average
}

void reset() { //function to reset the TMC
  on = false;
  for (int i = 48; i <= 60; i++) {  //turn all notes off
    MIDI.sendNoteOff(i, 127, 1);
  }
}

void measureAndCCsend(){ //function that gets measurements from the sensors and sends the corresponing Control Change numbers
  dist = getDistance();
  data1 = map(readDataFromSensor(sensor1_address), 260, 1022, 0, 127);  //some calibration on the sensor data
  data2 = map(readDataFromSensor(sensor2_address), 256, 1022, 0, 127);
  data3 = map(readDataFromSensor(sensor3_address), 260, 1022, 0, 127);

  if (data3 > 4) { //only send data more than 4 to minimise noise
    MIDI.sendControlChange(7, data3, 1);
  } else {
    data3 = 0;
  }
  if (data2 > 4) {
    MIDI.sendControlChange(12, data2, 1);
  } else {
    data2 = 0;
  }
  if (data1 > 4) {
    MIDI.sendControlChange(13, data1, 1);
  } else {
    data1 = 0;
  } 
}

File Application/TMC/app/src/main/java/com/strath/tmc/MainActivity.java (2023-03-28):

package com.strath.tmc; //unique package name

import android.content.pm.PackageManager;
import androidx.appcompat.app.AppCompatActivity;

//imports for the Graphical User Interface
import android.os.Bundle;
import android.view.View;
import android.widget.CheckBox;
import android.widget.Spinner;
import android.widget.Toast;
import android.widget.ToggleButton;

//imports for MIDI functionality
import android.media.midi.MidiDevice.MidiConnection;
import android.media.midi.MidiDeviceInfo;
import android.media.midi.MidiManager;

//imports from the provided Android Example
import com.example.android.common.midi.MidiOutputPortConnectionSelector;
import com.example.android.common.midi.MidiPortConnector;
import com.example.android.common.midi.MidiTools;

public class MainActivity extends AppCompatActivity {
    //variable initialisations
    boolean set = false;
    boolean effects_selected = false, sound_selected = false, spinner_selected = false;

    private MidiOutputPortConnectionSelector mPortSelector;




    @Override
    protected void onCreate(Bundle savedInstanceState) { //function is called when the app is opened
        super.onCreate(savedInstanceState);
        setContentView(R.layout.activity_main);

        SelectionConfig.init(false, 0, 0, 0); //initialise a SelectionConfig class

        //create variables for the spinner and the toggle button
        Spinner midi_spinner = (Spinner) findViewById(R.id.spinner_synth_sender);
        ToggleButton toggle = (ToggleButton) findViewById(R.id.tbSetReset); //initialise a toggle button
        //disable them
        toggle.setEnabled(false);
        midi_spinner.setEnabled(false);

        if (getPackageManager().hasSystemFeature(PackageManager.FEATURE_MIDI)) { //if statement to check if MIDI is supported
            setupMidi();
            //disable spinner
            midi_spinner.setEnabled(false);
            midi_spinner.setSelection(0);
            //disable toggle
            toggle.setAlpha(0.5f);
            toggle.setEnabled(false);
        } else{
            Toast.makeText(MainActivity.this, "MIDI not supported!", Toast.LENGTH_LONG).show(); //output an error if not supported

        }
    }

    private void setupMidi() {
        //variable initialisations required to setup the MIDI connection
        MidiManager midiManager;
        midiManager = (MidiManager) getSystemService(MIDI_SERVICE);
        MidiDeviceInfo synthInfo = MidiTools.findDevice(midiManager, "AndroidTest", "SynthExample");
        int portIndex = 0;
        mPortSelector = new MidiOutputPortConnectionSelector(midiManager, this, R.id.spinner_synth_sender, synthInfo, portIndex);
        mPortSelector.setConnectedListener(new MyPortsConnectedListener());
    }

    private void closeSynthResources() { //to close the port
        if (mPortSelector != null) {
            mPortSelector.close();
        }
    }

    private class MyPortsConnectedListener implements MidiPortConnector.OnPortsConnectedListener {
        @Override
        public void onPortsConnected(final MidiConnection connection) {
            runOnUiThread(() -> {
                if (connection == null) {
                    Toast.makeText(MainActivity.this, "Error: Device Not Connected", Toast.LENGTH_LONG).show();
                    mPortSelector.clearSelection();
                } else {
                    Toast.makeText(MainActivity.this, "Device Connected", Toast.LENGTH_LONG).show();
                }
            });
        }
    }

    @Override
    public void onDestroy() { //to stop everything
        closeSynthResources();
        super.onDestroy();
    }



    public void onCheckboxClicked(View view) { //when the checkbox is clicked this function executes

        //create variables for each checkbox and the toggle button
        CheckBox cb_sin = findViewById(R.id.cb_sin);
        CheckBox cb_saw = findViewById(R.id.cb_saw);

        CheckBox cb_pitch = findViewById(R.id.cb_pitch);
        CheckBox cb_duration = findViewById(R.id.cb_duration);
        CheckBox cb_bend_up = findViewById(R.id.cb_bend_up);
        CheckBox cb_bend_down = findViewById(R.id.cb_bend_down);

        ToggleButton toggle = (ToggleButton) findViewById(R.id.tbSetReset); //initialise a toggle button

        //code for setting sound id in config class and disabling the correct checkbox
        if(cb_sin.isChecked()){ //if it is checked, disable the other box
            cb_saw.setEnabled(false);
            SelectionConfig.setSound_id(1);
            sound_selected = true;
        } else if(cb_saw.isChecked()){
            cb_sin.setEnabled(false);
            SelectionConfig.setSound_id(2);
            sound_selected = true;
        } else{
            cb_sin.setEnabled(true);
            cb_saw.setEnabled(true);
            sound_selected = false;
        }

        //to set effect checkbox id in config class
        //this block is for the pitch effect with effect ID of 1
        if(cb_pitch.isChecked()){ //if the checkbox is checked
            if(SelectionConfig.getEffect_id1() == 0){ //only set values if they are 0
                SelectionConfig.setEffect_id1(1); //set the effect id
                //only set the value of the second effect is the current value of effect id 2 is 0 and effect id 1 is not the selected checkbox
            } else if(SelectionConfig.getEffect_id2() == 0 && SelectionConfig.getEffect_id1() != 1 ){
                SelectionConfig.setEffect_id2(1);
            }
        } else if (SelectionConfig.getEffect_id1() == 1){ //checks if when checkbox is unchecked, the effect value set is the one selected
            SelectionConfig.setEffect_id1(0); //if it is then reset the value back to 0
        } else if (SelectionConfig.getEffect_id2() == 1){
            SelectionConfig.setEffect_id2(0);
        }

        //this block is for the duration effect with effect ID of 2
        if(cb_duration.isChecked()) { //same as previous happens for each checkbox
            if (SelectionConfig.getEffect_id1() == 0) {
                SelectionConfig.setEffect_id1(2);
            } else if(SelectionConfig.getEffect_id2() == 0 && SelectionConfig.getEffect_id1() != 2 ){
                SelectionConfig.setEffect_id2(2);
            }
        } else if (SelectionConfig.getEffect_id1() == 2){
            SelectionConfig.setEffect_id1(0);
        } else if (SelectionConfig.getEffect_id2() == 2){
            SelectionConfig.setEffect_id2(0);
        }
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
